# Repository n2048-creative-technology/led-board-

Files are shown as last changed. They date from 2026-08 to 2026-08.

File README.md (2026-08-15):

# LED board

A wall of **584 addressable pixels** — eight identical segments of 73 — that
fills with light one pixel at a time, then breathes. A Seeed XIAO ESP32C3 on a
custom 24 V driver board runs all eight segments from a single hardware timer,
and raises its own Wi-Fi access point so colour, timing and power budget can be
changed from a phone with no app and no internet.

<p align="center">
  System overview: phone over Wi-Fi to a XIAO ESP32C3, one RMT signal fanned out through two SN74AHCT125N buffers to eight LED connectors, with a 24 V supply and an on-board buck converter
</p>

| | |
|---|---|
| Controller | Seeed Studio XIAO ESP32C3 on the `otherworlds-v2` driver board |
| Output | 8 segments × 73 px = **584** WS281x, colour order GBR, 800 kHz, 24 V |
| Frame rate | **63 fps** with the access point running |
| Control | Wi-Fi AP `LED-Board` / `ledboard` → <http://4.3.2.1/> |
| Persistence | All settings in NVS, survive a power cycle |

---

## Contents

- [How it behaves](#how-it-behaves)
- [Web UI](#web-ui)
- [HTTP API](#http-api)
- [Driving 8 outputs from a 2-channel chip](#driving-8-outputs-from-a-2-channel-chip)
- [The driver board](#the-driver-board)
- [Firmware hardware map](#firmware-hardware-map)
- [Power](#power)
- [Build, flash, monitor](#build-flash-monitor)
- [Repository layout](#repository-layout)
- [Status](#status)

---

## How it behaves

Power-up runs a two-stage sequence, identical and in step across all eight
segments:

1. **FILL** — the segment fades up pixel by pixel from the first to the last,
   with a soft leading edge spanning a settable number of pixels.
2. **BREATHE** — once full, brightness cycles between 100% and a settable floor,
   forever.

Turning the lights off runs the fill **backwards**: the pixels withdraw in
exactly the reverse order they arrived, so the last to light is the first to go
dark. Pressing off mid-sweep picks up at the matching front position rather than
snapping, so it stays smooth even if you change your mind halfway.

<p align="center">
  Phase machine FILL to BREATHE to EMPTY to OFF, five snapshots of the fill front travelling along a segment, and the breathing brightness curve
</p>

<p align="center">
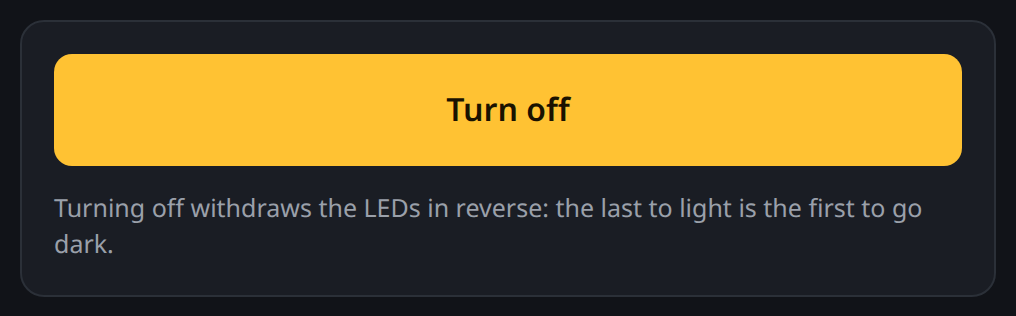
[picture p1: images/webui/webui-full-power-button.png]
Power card showing a bright Turn off button
  
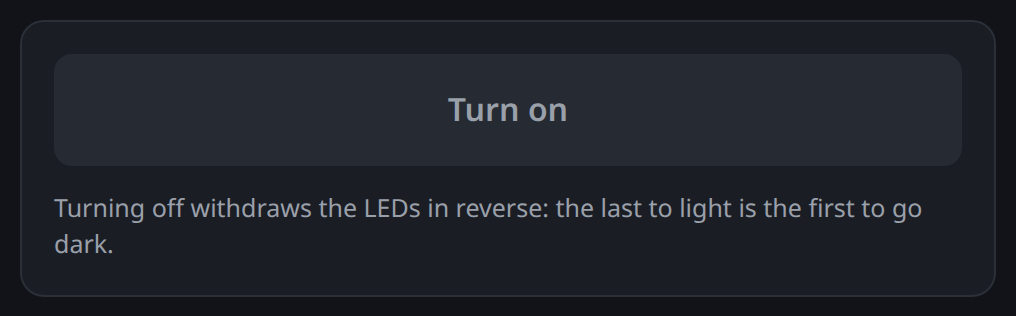
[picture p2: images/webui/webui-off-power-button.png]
The same card with the lights off, showing a dimmed Turn on button
  
</p>

The pixel levels in that diagram are not an illustration — they are computed by
running the firmware's own integer maths (`renderFrontAt()`, `breatheWave()` and
NeoPixel's gamma-2.6 table) outside the chip. The fade is gamma-corrected so it
ramps evenly to the eye instead of spending most of its apparent brightness in
the first few percent.

## Web UI

The board raises its own access point with a captive portal. Join the network
and the "sign in to network" sheet should open the UI by itself; if not, browse
to the address.

| | |
|---|---|
| SSID | `LED-Board` |
| Password | `ledboard` |
| Address | <http://4.3.2.1/> |

Everything on the page is inline — no CDN is reachable on an access point — so
the colour wheel is drawn on a `<canvas>` rather than pulled from a library.

<p align="center">
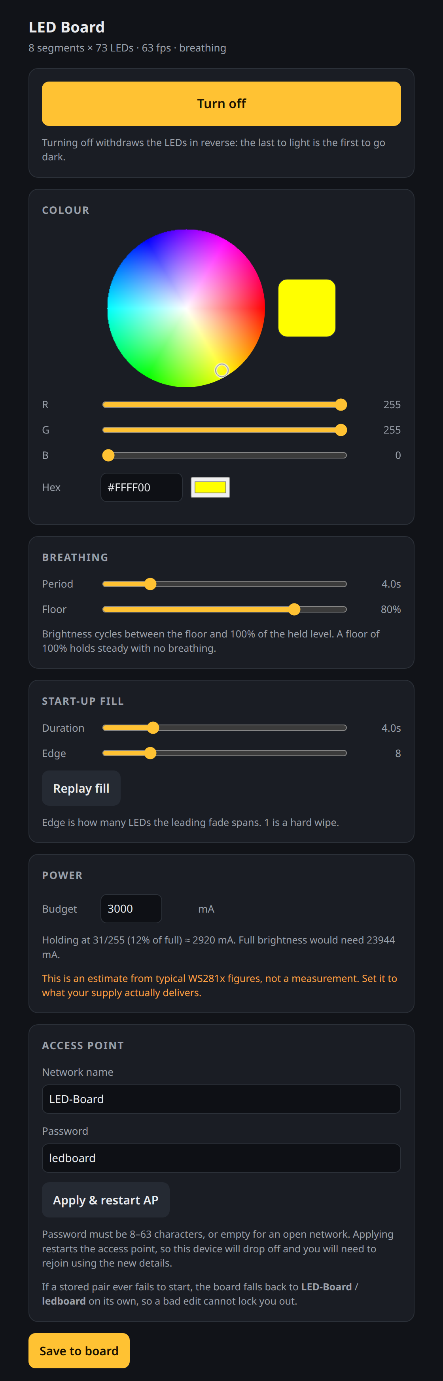
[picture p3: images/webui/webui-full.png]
The full control page: power button, colour wheel with RGB sliders and hex field, breathing controls, start-up fill controls, power budget, and access point settings
  
  &nbsp;&nbsp;
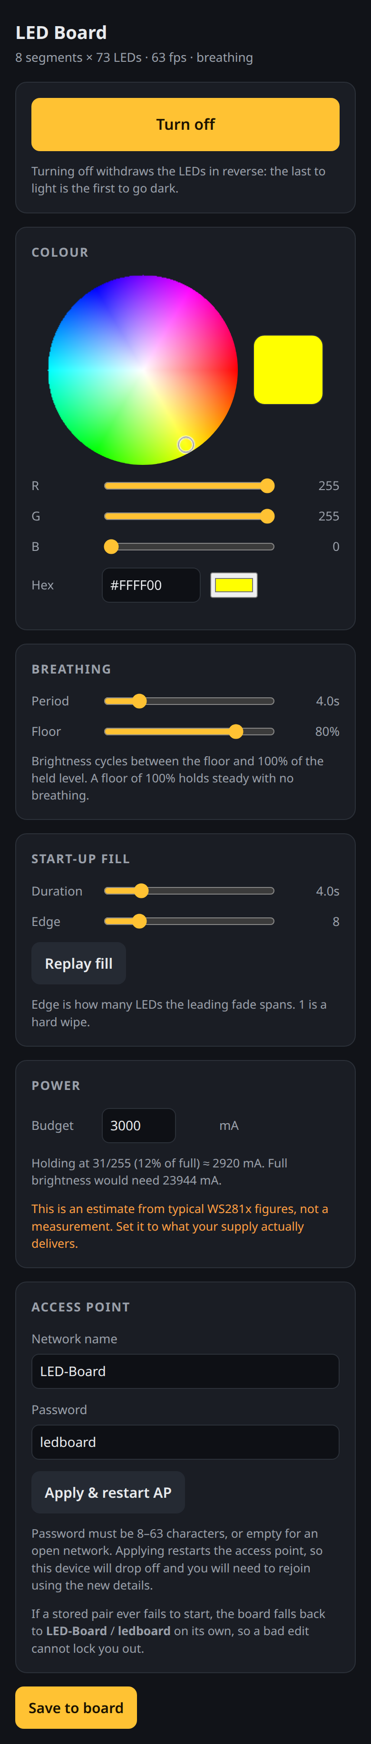
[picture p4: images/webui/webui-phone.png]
The same page at phone width, laying out in a single column
  
</p>

<sub>Left: the page as served, at its 520 px maximum width. Right: the same page
at 390 px — it is a single responsive column, which is how it will actually be
used.</sub>

### Colour

An HSV wheel (drag to pick), R/G/B sliders, a hex field, and the OS-native
colour picker. All four stay in sync, and changes are pushed to the strip live,
debounced at ~60 ms.

<p align="center">
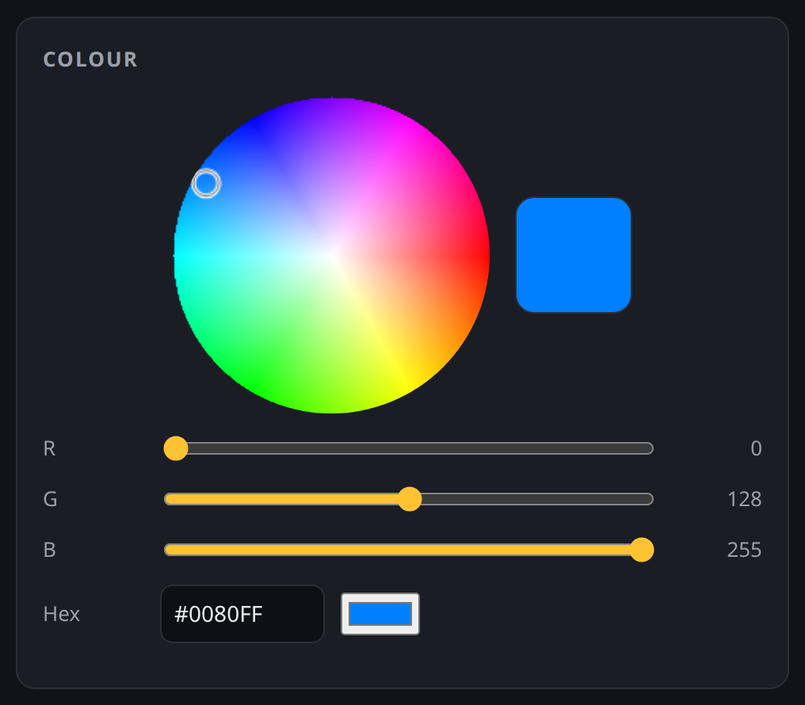
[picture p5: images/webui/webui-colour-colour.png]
Colour card with the wheel, a swatch, R/G/B sliders reading 0/128/255, and the hex field reading #0080FF
  
</p>

### Breathing and start-up fill

<p align="center">
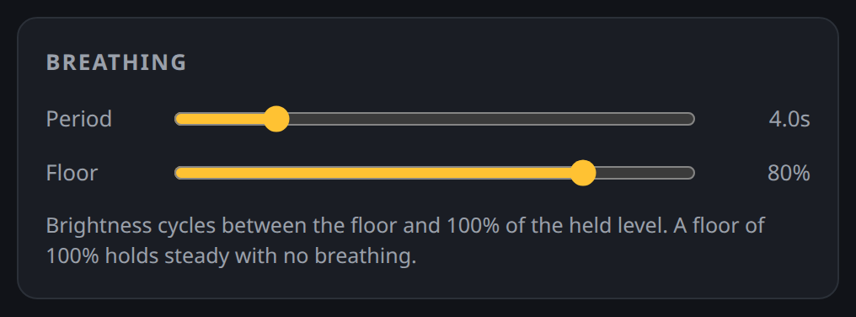
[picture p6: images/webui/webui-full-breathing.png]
Breathing card: period slider at 4.0 s and floor slider at 80 percent
  
</p>

<p align="center">
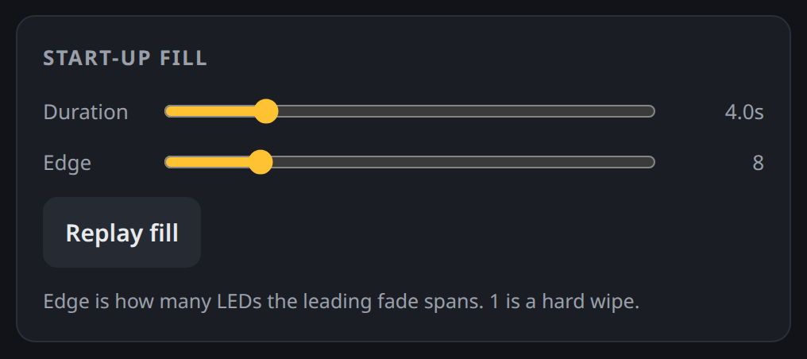
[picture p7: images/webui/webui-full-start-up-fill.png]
Start-up fill card: duration slider at 4.0 s, edge slider at 8 pixels, and a Replay fill button
  
</p>

Period runs 0.5–20 s; a floor of 100% holds steady with no breathing. *Replay
fill* restarts the fill animation so it can be watched again without a reboot.
Edge is how many pixels the leading fade spans — 1 is a hard wipe.

### Power

The budget, with live feedback on the resulting hold level and estimated draw.
The limiter accounts for the *current colour*: red lights one channel, yellow
two, white three, so the achievable brightness changes as you pick. Read
[Power](#power) before trusting the milliamp figure on this 24 V board.

<p align="center">
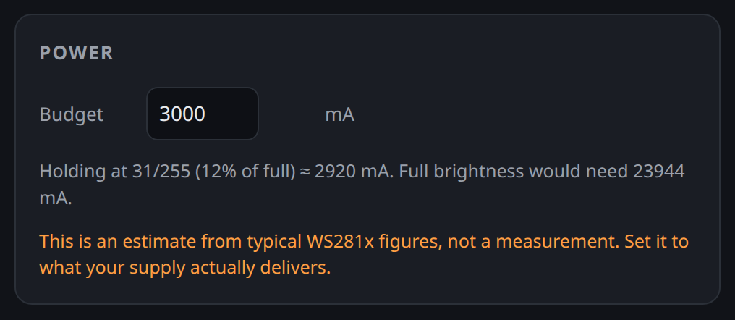
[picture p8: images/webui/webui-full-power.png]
Power card at a 3000 mA budget, reporting a hold of 31 of 255 and about 2920 mA
  
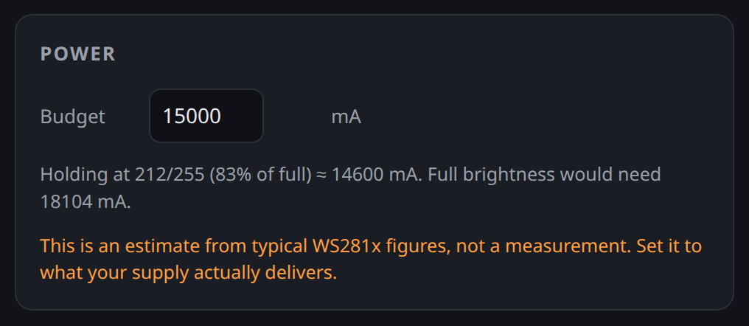
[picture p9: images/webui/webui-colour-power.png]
Power card at a 15000 mA budget, reporting a hold of 212 of 255 and about 14600 mA
  
</p>

<sub>The same card at a 3000 budget (left) and 15000 with a blue-ish colour
selected (right). Both numbers come from the firmware's own estimator.</sub>

### Access point — you cannot lock yourself out

<p align="center">
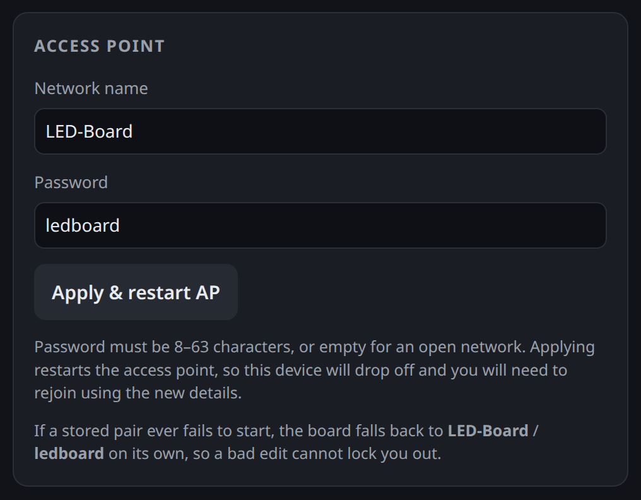
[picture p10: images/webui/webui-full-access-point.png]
Access point card with editable network name and password fields and an Apply and restart AP button
  
</p>

Credentials are validated server-side before being stored: SSID 1–32 characters,
password empty for an open network or 8–63 characters. A 1–7 character password
is rejected, since no access point will start with one. On top of that, if a
stored pair ever fails to bring the AP up, the board falls back to `LED-Board` /
`ledboard` by itself. **Recovering never requires reflashing over USB.**

Applying restarts the radio, so the phone will drop off and must rejoin with the
new details. The HTTP reply is sent ~400 ms before the restart, so the browser
always sees the response.

### Saving

Changes apply live. **Save to board** writes them to NVS so they survive a power
cycle; without saving, the board reverts to its defaults on reboot — including
the on/off state, so a board saved "off" comes back off.

## HTTP API

Handy for scripting or an external controller. All values are clamped
server-side, so out-of-range input is safe.

| Endpoint | Purpose |
|---|---|
| `GET /api/state` | Current settings, hold level, estimated mA, fps, phase |
| `GET /api/set?r=&g=&b=&bp=&bm=&fd=&fe=&pb=` | Set any subset; returns the new state |
| `GET /api/power?on=0\|1` | Turn off (reverse withdraw) or on (fill) |
| `GET /api/ap?ssid=&pass=` | Change AP credentials; `400` if invalid |
| `GET /api/fill` | Restart the fill animation |
| `GET /api/save` | Persist current settings to NVS |

Parameters: `r` `g` `b` 0–255 · `bp` breathe period ms 200–120000 · `bm` breathe
floor % 0–100 · `fd` fill duration ms 100–120000 · `fe` fill edge px 1–73 ·
`pb` power budget 100–40000.

`phase` reports `filling`, `breathing`, `emptying` or `off`.

```console
$ curl "http://4.3.2.1/api/state"
{"on":true,"ssid":"LED-Board","pass":"ledboard","r":255,"g":255,"b":0,
 "bp":4000,"bm":80,"fd":4000,"fe":8,"pb":3000,"hold":31,"ma":2920,
 "maFull":23944,"fps":63,"phase":"breathing"}
```

Wi-Fi does not disturb the LED output — the strips are driven by the RMT
peripheral in hardware, and the frame rate stayed at 62–63 fps with the AP up
and a client connected.

## Driving 8 outputs from a 2-channel chip

The ESP32-C3 has only **2 RMT TX channels**, which rules out both obvious
approaches. The firmware instead transmits **one** segment's worth of data on a
single RMT channel bound to GPIO3, then uses the GPIO matrix
(`esp_rom_gpio_connect_out_signal`) to route that same output signal to the
other seven pins. Every segment gets an identical, hardware-timed waveform, and
a frame costs one transmission (~2.2 ms) instead of eight.

<p align="center">
  Frame buffer to one RMT TX channel to the GPIO matrix, mirrored out to eight GPIOs, with a comparison of three driver approaches
</p>

**The trade-off:** all 8 segments necessarily show the *same* content. That is
exactly what this piece wants. If independent per-segment animation is ever
needed, the options are:

- **2 independent strips** via FastLED (the chip's real RMT limit), or
- **8 independent strips** via a parallel bit-bang driver, computing an 8-bit
  GPIO mask per bit period — all eight pins live in one 32-bit output register,
  so this is feasible but needs cycle-accurate timing work, or
- **a chip with more RMT channels** — ESP32-S3 has 4, the original ESP32 has 8.

## The driver board

KiCad project: [`electronics/otherworlds-v2.kicad_pro`](electronics/otherworlds-v2.kicad_pro).
Two-layer, **98.7 × 90.9 mm**, 1.6 mm, four M4 mounting holes, through-hole
throughout so it can be built by hand.

<p align="center">
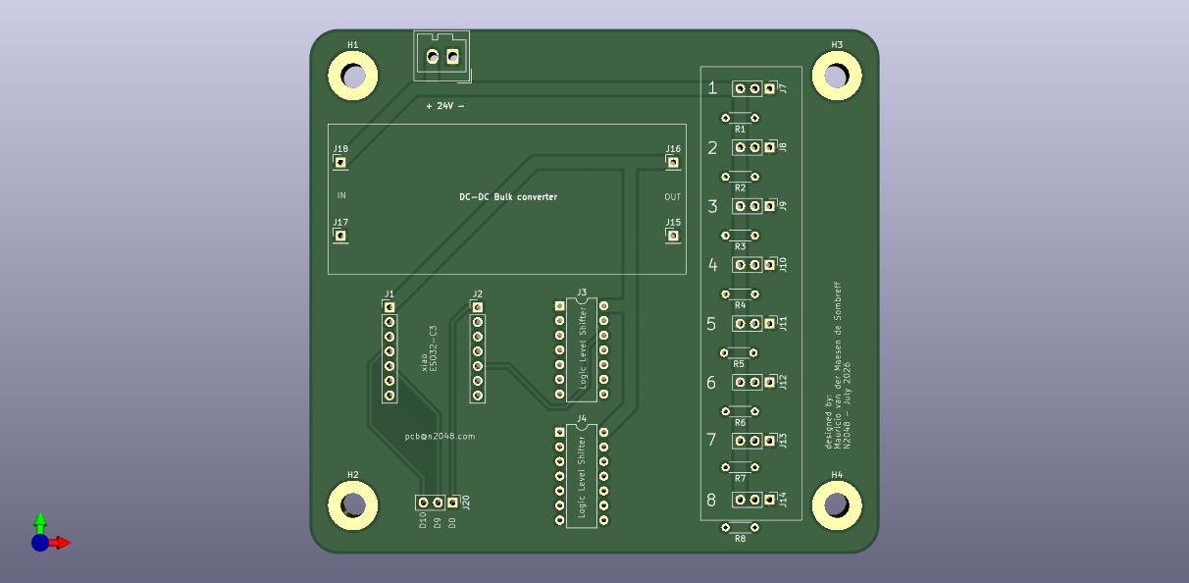
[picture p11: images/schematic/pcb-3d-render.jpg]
3D render of the driver board: 24 V Wago input top left, DC-DC buck converter area, XIAO on two 7-pin headers, two level shifter DIPs, and eight numbered 3-pin LED connectors with series resistors down the right edge
  
</p>

<p align="center">
  KiCad schematic: XIAO headers, two SN74AHCT125N level shifters with eight 220 ohm series resistors, eight 3-pin LED connectors, DC-DC buck converter headers, and a 24 V input
</p>

<sub>Exported from
<a href="electronics/otherworlds-v2.kicad_sch">otherworlds-v2.kicad_sch</a> with
<code>kicad-cli</code>. Also available as
<a href="images/schematic/otherworlds-v2.pdf">PDF</a>, and the layers as
<a href="images/schematic/pcb-front.svg">front</a> /
<a href="images/schematic/pcb-back.svg">back</a> SVG.</sub>

### Signal path

<p align="center">
  One channel: XIAO D1 into an SN74AHCT125N buffer, out through a 220 ohm resistor to connector J7 pin 2, with 24 V on pin 3 and a shared ground
</p>

Each of the eight channels is the same four parts:

**XIAO Dn → SN74AHCT125N buffer → 220 Ω → LED connector pin 2.**

The buffers run from the on-board 5 V rail. AHCT-family logic takes a 3.3 V
input as a valid high and drives a full 5 V output, which is what gets the data
line clear of a WS281x input threshold — the XIAO's own 3.3 V swing is marginal
and fails intermittently on a long lead.

Only the data line passes through the board's logic side; **+24 V goes straight
from the Wago input to pin 3 of every LED connector** and never touches it.

### Bill of materials

From [`electronics/production/bom.csv`](electronics/production/bom.csv):

| Ref | Part | Qty | Footprint |
|---|---|---|---|
| J3, J4 | SN74AHCT125N quad buffer | 2 | DIP-14, 7.62 mm |
| R1–R8 | 220 Ω | 8 | Axial DIN0204, 5.08 mm |
| J1, J2 | 1×7 pin header — the XIAO | 2 | 2.54 mm vertical |
| J7–J14 | 1×3 pin header — LED segments 1–8 | 8 | 2.54 mm vertical |
| J15–J18 | 1×1 pin header — buck converter module | 4 | 2.54 mm vertical |
| J19 | Wago 734-132 — 24 V input | 1 | 3.50 mm vertical |
| J20 | 1×3 pin header — D0/D9/D10 breakout | 1 | 2.54 mm vertical |
| H1–H4 | M4 mounting hole, plated | 4 | 4.3 mm |

The DC-DC buck converter is a **module**, not a fitted part: it sits on the four
single-pin headers (`J18`/`J17` in, `J16`/`J15` out), so it can be sized to the
5 V load and swapped without touching the board.

`J20` breaks out D0, D9 and D10 — the three pins the LED channels do not use.
D0/GPIO2 and D9/GPIO9 are strapping pins; read
[the pinout notes](firmware/docs/xiao-esp32c3-pinout.md) before hanging anything
off them.

### Connector map

Traced through the netlist exported from the committed schematic — not read off
the drawing:

| Connector (silkscreen) | J7 (1) | J8 (2) | J9 (3) | J10 (4) | J11 (5) | J12 (6) | J13 (7) | J14 (8) |
|---|---|---|---|---|---|---|---|---|
| Net | L1 | L2 | L3 | L4 | L5 | L6 | L7 | L8 |
| Resistor | R1 | R2 | R3 | R4 | R5 | R6 | R7 | R8 |
| Buffer | J3 | J3 | J3 | J3 | J4 | J4 | J4 | J4 |
| XIAO pin | D1 | D2 | **D4** | **D3** | D5 | D6 | **D8** | **D7** |
| GPIO | 3 | 4 | 6 | 5 | 7 | 21 | 8 | 20 |

Note the two crossed pairs: J9/J10 are fed by D4/D3, and J13/J14 by D8/D7. That
is harmless here — every output carries the identical waveform, so which pin
lands on which connector cannot change what the wall does — but it is worth
knowing before probing a channel with a scope.

Every LED connector is wired the same way: **pin 1 = GND, pin 2 = data,
pin 3 = +24 V**.

> ⚠️ **The working copy of the schematic is mid-edit and currently inconsistent.**
> In `HEAD` every data label appears exactly twice (once at the XIAO header,
> once at a buffer input). In the uncommitted file, `D1` and `D2` appear only
> once each while `D7` and `D8` appear three times — the two labels at J3's
> first inputs now read D7/D8, so those buffers would be driven in parallel with
> J4's and D1/D2 would drive nothing. Because all eight channels carry the same
> waveform, the piece would still *look* correct, which is what makes it worth
> catching. The table above comes from `HEAD`; re-run
> `bash scripts-tools/export-kicad.sh` and re-check it once the edits land.

## Firmware hardware map

| | |
|---|---|
| Board | Seeed Studio XIAO ESP32C3 (`seeed_xiao_esp32c3`) |
| MCU | ESP32-C3, single-core RISC-V @ 160 MHz, 4 MB flash |
| Platform | pioarduino `espressif32` 54.3.20 — Arduino core 3.2.0, ESP-IDF 5.4 |
| LED library | Adafruit NeoPixel 1.15.5 (FastLED 3.10.3 kept for colour helpers) |
| Strip | WS281x, 800 kHz, colour order **GBR**, 24 V |
| Segments | 8 × 73 px = 584 total |
| Data pins | D1–D8 = GPIO 3, 4, 5, 6, 7, 21, 20, 8 |
| Serial | Native USB Serial/JTAG, 115200 baud |

Strip parameters (WS281x / GBR / 73) were taken from a WLED configuration
confirmed working on this exact hardware — worth keeping as the reference if
anything ever regresses. `73` counts **control ICs**, not LED packages: a 24 V
strip usually groups several physical LEDs behind each addressable pixel.

D1/GPIO3 carries the master signal because it is **not** a strapping pin, so an
attached strip cannot interfere with boot the way D0/D8/D9 could.

> **There is no GPIO22 on the ESP32-C3** — its GPIO range is 0–21. D7 is
> **GPIO20** (UART0 RX), which is what the seventh segment uses.

Full pin map, strapping-pin traps and the BOOT-button recovery procedure:
[firmware/docs/xiao-esp32c3-pinout.md](firmware/docs/xiao-esp32c3-pinout.md).

## Power

Adafruit NeoPixel has no power management of its own, so the firmware includes a
limiter: it finds the brightest scaling of the chosen colour that fits
`powerBudgetMa` and holds there, which is why the UI reports a *hold level*
rather than simply obeying the brightness you asked for.

### The estimator models a 5 V strip

> ⚠️ **The milliamp figures the firmware reports are a 5 V-strip model** —
> 20 mA per channel per pixel at full, plus 1 mA idle per controller IC. **This
> board runs the strips at 24 V**, where the current drawn from the supply is a
> different number entirely (roughly the strip's rated W/m × length ÷ 24 V).
>
> So on this hardware, treat the budget as **a brightness cap in the firmware's
> own units**, not as amps at the PSU. Size the actual supply from the strip's
> rating, measure the real draw, and then pick the budget that lands on a
> brightness you can afford.

What the limiter does with a given budget, for yellow (255, 255, 0) across all
584 pixels — these are the numbers the UI will show:

| Budget | Hold level | Fraction of full | Reported draw |
|---|---|---|---|
| 3000 (default) | 31/255 | 12% | 2920 |
| 5000 | 50/255 | 20% | 4672 |
| 10000 | 108/255 | 42% | 9928 |
| 15000 | 159/255 | 62% | 14600 |
| 20000 | 216/255 | 85% | 19856 |
| 24000+ | 255/255 | 100% | 23944 |

Colour changes the arithmetic completely. At full brightness the estimator
reports roughly **12264** for a single-channel colour (red, green, blue),
**23944** for a two-channel one (yellow, cyan, magenta) and **35624** for white
— so the same budget buys a much brighter red than white.

Whatever the voltage, two things still hold: **inject power at both ends of each
segment** (and mid-run on long ones), and expect a visible colour shift toward
red wherever the supply sags.

## Build, flash, monitor

```bash
cd firmware
pio run                    # build
pio run -t upload          # build + flash
pio device monitor         # 115200 baud
```

Last verified build (2026-08-15, `pio run`):

```
RAM:   [=         ]  11.6% (used 37944 bytes from 327680 bytes)
Flash: [========  ]  77.6% (used 1017378 bytes from 1310720 bytes)
========================= [SUCCESS] Took 12.66 seconds =========================
```

### Testing without a strip

The firmware self-reports over serial, so it can be validated with nothing
attached — the RMT peripheral will happily clock data into thin air, and the
per-2-second heartbeat reports phase, level, frame rate, estimated draw and the
number of connected Wi-Fi clients.

```
XIAO ESP32C3 - LED board
8 segments x 73 LEDs = 584 total | WS281x 800 kHz, order GBR
Pins: D1=GPIO3 D2=GPIO4 D3=GPIO5 D4=GPIO6 D5=GPIO7 D6=GPIO21 D7=GPIO20 D8=GPIO8
  RMT signal 87 on GPIO3 -> mirrored to: GPIO4 GPIO5 GPIO6 GPIO7 GPIO21 GPIO20 GPIO8
Colour 255,255,0 | budget 3000 mA -> hold 31/255 (est. 2920 mA, full 23944 mA)
AP "LED-Board" up -> http://4.3.2.1/  (password: ledboard)
PHASE: FILL
[    2000 ms] FILL    | level  31/255 | 62 fps | est. 2920 mA | clients 0
PHASE: BREATHE
[    4000 ms] BREATHE | level  27/255 | 63 fps | est. 2607 mA | clients 1
```

<sub>Format derived from the <code>Serial.printf</code> calls in
<code>main.cpp</code>; the RMT signal number is whatever the driver was
assigned. Not yet captured from hardware — see <a href="#status">Status</a>.</sub>

Three things to check first if something looks wrong:

- **Garbled colours or flicker** → wrong chipset timing. `PIXEL_TYPE` is
  `NEO_GBR + NEO_KHZ800`.
- **Colours swapped** (yellow shows as something else) → wrong byte order. Swap
  the letters in the `NEO_GBR` half of `PIXEL_TYPE`; common variants are `GRB`,
  `RGB` and `BRG`.
- **`FAN-OUT FAILED: GPIO3 has no peripheral signal`** → the RMT channel never
  bound to the master pin, so only segment 1 would light. Everything downstream
  depends on that line succeeding.

## Repository layout

```
electronics/          KiCad project "otherworlds-v2" — schematic, PCB, production files
  production/         Gerbers, BOM, positions (JLCPCB fabrication toolkit output)
firmware/             PlatformIO project
  src/main.cpp        the whole firmware: animation, power limiter, AP, web UI
  docs/               pinout and GPIO caveats
images/
  diagrams/           SVG diagrams (generated)
  schematic/          KiCad exports + the 3D render
  webui/              web UI screenshots (generated)
scripts-tools/        the generators for everything in images/
```

### Regenerating the documentation assets

All three generators are deterministic; only the KiCad exports need KiCad
installed, and none of them need hardware:

```bash
python3 scripts-tools/mkshots.py      # -> images/webui/*.png
python3 scripts-tools/mkdiagrams.py   # -> images/diagrams/*.svg
bash    scripts-tools/export-kicad.sh # -> images/schematic/*
```

`mkshots.py` lifts the page straight out of the `R"HTML(...)HTML"` literal in
`firmware/src/main.cpp`, replaces `window.fetch` with a shim that reimplements
the `/api/*` handlers — including the integer power maths — and screenshots the
result in headless Chrome. So the screenshots track the firmware: change the UI,
re-run, and the README is current. `mkdiagrams.py` likewise computes the
animation diagram from the firmware's own rendering maths. Details in
[scripts-tools/README.md](scripts-tools/README.md).

## Status

| Step | Status |
|---|---|
| PCB designed, fabrication files exported | ✅ `otherworlds-v2`, July 2026 |
| Builds for `seeed_xiao_esp32c3` | ✅ 2026-08-15 — RAM 11.6%, flash 77.6% |
| Web UI rendered and exercised | ✅ against a faithful mock of the device API |
| Flashed and run on hardware | ⏳ pending — no board on USB at time of writing |
| Board brought up with strips attached | ⏳ pending |
| Measured current draw | ⏳ pending — all power figures are estimates, and the estimator assumes 5 V |

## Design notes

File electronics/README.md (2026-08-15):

# Electronics — `otherworlds-v2`

KiCad 9 project for the LED driver board: a XIAO ESP32C3 carrier that buffers
its eight data outputs to 5 V and hands them to eight 24 V LED segments.

Open [`otherworlds-v2.kicad_pro`](otherworlds-v2.kicad_pro). Rendered exports of
the schematic and layers live in [`../images/schematic/`](../images/schematic)
and are regenerated with `bash ../scripts-tools/export-kicad.sh`.

| | |
|---|---|
| Size | 98.7 × 90.9 mm, 1.6 mm, 2 layer |
| Mounting | 4 × M4 plated holes (H1–H4) |
| Assembly | Through-hole throughout — hand-solderable |
| Input | 24 V via Wago 734-132 (J19) |
| Logic supply | DC-DC buck module on J15–J18, 24 V → 5 V |

## Signal path

Eight identical channels:

```
XIAO Dn ─► SN74AHCT125N (J3 for D1-D4, J4 for D5-D8) ─► 220 Ω (Rn) ─► LED connector pin 2
```

AHCT logic runs from 5 V and accepts 3.3 V as a valid high, so it both level
shifts and buffers: the strip sees a full 5 V edge instead of the XIAO's
marginal 3.3 V. The series resistor damps reflections and sits at the driver
end of the line.

+24 V runs from J19 straight to pin 3 of every LED connector. It never enters
the logic side of the board.

## Connector map

Traced through the netlist of the committed schematic:

| Connector | J7 (1) | J8 (2) | J9 (3) | J10 (4) | J11 (5) | J12 (6) | J13 (7) | J14 (8) |
|---|---|---|---|---|---|---|---|---|
| Net | L1 | L2 | L3 | L4 | L5 | L6 | L7 | L8 |
| Resistor | R1 | R2 | R3 | R4 | R5 | R6 | R7 | R8 |
| Buffer | J3 | J3 | J3 | J3 | J4 | J4 | J4 | J4 |
| XIAO pin | D1 | D2 | **D4** | **D3** | D5 | D6 | **D8** | **D7** |
| GPIO | 3 | 4 | 6 | 5 | 7 | 21 | 8 | 20 |

J9/J10 and J13/J14 are fed by crossed pairs. Harmless — the firmware drives all
eight outputs with one identical waveform — but worth knowing at the bench.

LED connectors are all **pin 1 = GND, pin 2 = data, pin 3 = +24 V**.

> ⚠️ The working copy is currently mid-edit: `D1`/`D2` appear once each and
> `D7`/`D8` three times, i.e. J3's first two inputs are labelled D7/D8 rather
> than D1/D2. In `HEAD` every label appears exactly twice. See the root
> [README](../README.md#connector-map).

Other headers:

| Ref | Purpose |
|---|---|
| J1 / J2 | XIAO ESP32C3, 1×7 each |
| J15–J18 | Buck module: J18/J17 = 24 V in, J16/J15 = 5 V out |
| J19 | 24 V input, Wago cage clamp |
| J20 | Breakout of the three unused pins: D0, D9, D10 |

⚠️ D0/GPIO2 and D9/GPIO9 on J20 are **strapping pins**. Anything wired there can
stop the board booting — read
[../firmware/docs/xiao-esp32c3-pinout.md](../firmware/docs/xiao-esp32c3-pinout.md)
first.

## Fabrication

[`production/`](production) holds the JLCPCB fabrication-toolkit output:
[`otherworlds-v2.zip`](production/otherworlds-v2.zip) (gerbers),
[`bom.csv`](production/bom.csv), [`positions.csv`](production/positions.csv),
[`designators.csv`](production/designators.csv) and an IPC netlist. Settings are
in [`fabrication-toolkit-options.json`](fabrication-toolkit-options.json).

Everything is through-hole, so the BOM carries no LCSC part numbers — it is a
hand-assembly list, not an assembly-service one.

## Sizing the supply

Work from the strip's rating, not from the firmware's estimate: the firmware's
milliamp figures model a 5 V strip, while these segments run at 24 V. Take the
strip's W/m × total length ÷ 24 V, add margin, and fuse the input. Inject at
both ends of each segment.

Details, and what the firmware's budget number actually controls, in the root
[README](../README.md#power).

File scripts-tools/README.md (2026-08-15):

# Documentation generators

Everything in [`images/`](../images) is generated by these scripts. Nothing here
needs hardware attached.

| Script | Output | What it does |
|---|---|---|
| `mkshots.py` | `images/webui/*.png` | Screenshots of the ESP32-served web UI |
| `mkdiagrams.py` | `images/diagrams/*.svg` | The four README diagrams |
| `export-kicad.sh` | `images/schematic/*` | Schematic SVG + PDF, PCB layer SVGs, 3D render |
| `rasterize.sh` | `*.png` beside each SVG | Preview render of an SVG, via Chrome |

```bash
python3 scripts-tools/mkshots.py
python3 scripts-tools/mkdiagrams.py
bash    scripts-tools/export-kicad.sh
```

Requires `google-chrome` on `PATH`, Pillow for `mkshots.py`, and KiCad for
`export-kicad.sh` — it finds either `kicad-cli` or the snap's
`kicad.kicad-cli`. The snap is confined to `$HOME`, which is why the export
script always writes inside the repo.

## How the screenshots stay honest

`mkshots.py` does not keep a copy of the page. It extracts the
`R"HTML(...)HTML"` literal out of `firmware/src/main.cpp` at run time, then
injects a shim that replaces `window.fetch` with a reimplementation of the
firmware's `/api/*` handlers — including the integer power maths
(`estimateMilliamps` / `computeHoldLevel`), so the hold level and mA readouts on
screen are the numbers the board would actually report. Change the UI in the
firmware, re-run, and the README is current.

The variants captured (default yellow, lights off, another colour at a 15 A
budget, phone width) are the `shoot(...)` calls at the bottom of the file. Card
crops come from bounding boxes measured in the live page, not fixed pixel
offsets, so they survive layout changes.

## How the diagrams stay honest

`mkdiagrams.py` writes SVG directly. The animation diagram is not drawn by hand:
`strip_levels()` and `breathe_wave()` are line-by-line ports of `renderFrontAt()`
and `breatheWave()` from `main.cpp`, gamma table included, so the LED gradients
and the breathing curve are the firmware's real output.

## Do not use ImageMagick on these SVGs

`convert` falls back to ImageMagick's internal SVG renderer here, which silently
drops `fill-opacity` (every LED renders fully lit) and mis-measures text.
`rasterize.sh` goes through Chrome instead:

```bash
scripts-tools/rasterize.sh images/diagrams/animation.svg
```

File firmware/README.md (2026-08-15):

# LED board

Firmware for a Seeed **XIAO ESP32C3** driving addressable RGB LED strips.

Current behaviour, across **8 identical strip segments** (73 LEDs each, 584
total) on D1–D8:

1. **FILL** — every segment fades up to bright yellow, LED by LED from the
   first to the last, with a soft leading edge. All 8 segments run this in
   parallel and in step.
2. **BREATHE** — once full, brightness breathes between 100% and 80% of the
   held level, forever.

## Wi-Fi control

The board raises its own access point with a captive portal, so it can be
controlled from a phone with no app and no internet.

| | |
|---|---|
| SSID | `LED-Board` |
| Password | `ledboard` |
| Address | http://4.3.2.1/ |

Join the network and the "sign in" sheet should open the UI automatically; if
not, browse to the address. Everything on the page is inline — no CDN is
reachable on an AP, so the colour wheel is drawn on a `<canvas>` rather than
pulled from a library.

The UI offers:

- **On / off** — turning off runs the fill animation **backwards**, so the
  LEDs withdraw in exactly the reverse order they arrived: the last LED to
  light is the first to go dark. Pressing the button mid-sweep picks up at the
  matching front position rather than snapping, so it stays smooth even if you
  change your mind halfway.
- **Colour** — an HSV wheel (drag to pick), R/G/B sliders, a hex field, and
  the OS-native colour picker. All four stay in sync.
- **Breathing** — cycle period (0.5–20 s) and floor (0–100%). A floor of 100%
  holds steady with no breathing.
- **Start-up fill** — duration, leading-edge softness in LEDs, and a *Replay
  fill* button to watch it again without a reboot.
- **Power** — the budget in mA, with live feedback on the resulting hold level
  and estimated draw. The limiter accounts for the *current colour*: red uses
  one channel, yellow two, white three, so the achievable brightness changes
  as you pick.
- **Access point** — editable network name and password. Applying restarts the
  radio, so you will be disconnected and must rejoin with the new details.

### You cannot lock yourself out of the AP

Credentials are validated server-side before being stored (SSID 1–32 chars,
password empty for an open network or 8–63 chars — a 1–7 char password is
rejected, since no AP will start with one). On top of that, if a stored pair
ever fails to bring the AP up, the board falls back to `LED-Board` /
`ledboard` by itself. Recovering never requires reflashing over USB.

Changes apply live (debounced ~60 ms). **Save to board** writes them to NVS so
they survive a power cycle; without saving, the board reverts to defaults on
reboot.

### HTTP API

Handy for scripting or an external controller:

| Endpoint | Purpose |
|---|---|
| `GET /api/state` | Current settings, hold level, estimated mA, fps, phase |
| `GET /api/set?r=&g=&b=&bp=&bm=&fd=&fe=&pb=` | Set any subset; returns new state |
| `GET /api/power?on=0\|1` | Turn off (reverse withdraw) or on (fill) |
| `GET /api/ap?ssid=&pass=` | Change AP credentials; 400 if invalid |
| `GET /api/fill` | Restart the fill animation |
| `GET /api/save` | Persist current settings to NVS |

`phase` reports `filling`, `breathing`, `emptying` or `off`.

All values are clamped server-side, so out-of-range input is safe.

Wi-Fi does not disturb the LED output — the strips are driven by the RMT
peripheral in hardware, and the frame rate stayed at 62 fps with the AP
running.

## ⚠️ Power: yellow at this scale is expensive

584 LEDs, and **yellow lights two channels per LED**. Full-brightness yellow
across all segments is an estimated **~24 A at 5 V (~120 W)**.

The firmware includes a limiter (Adafruit NeoPixel has no power management of
its own) that computes the brightest yellow fitting `POWER_BUDGET_MA` and
holds there. At the placeholder **3000 mA** it settles on level **31/255 —
about 12% of full**, which is not "bright" by any reasonable reading.

**Set `POWER_BUDGET_MA` in [src/main.cpp](src/main.cpp) to what your supply
actually delivers.** Roughly what each budget buys:

| PSU budget | Hold level | Fraction of full |
|---|---|---|
| 3 A (placeholder) | 31/255 | ~12% |
| 10 A | ~106/255 | ~42% |
| 15 A | ~160/255 | ~63% |
| 20 A | ~213/255 | ~84% |
| 24 A+ | 255/255 | 100% |

Injecting power at both ends of each segment (and mid-run for long ones) is
also worth planning — 24 A does not travel far down a strip's copper without
a visible voltage drop and a colour shift toward red.

## Driving 8 outputs from a 2-channel chip

The ESP32-C3 has only **2 RMT TX channels**, which rules out both obvious
approaches:

| Approach | Result |
|---|---|
| FastLED 3.10.3, 8 controllers | ❌ `no free tx channels`, then a Guru Meditation panic. FastLED pins one RMT channel per controller for its lifetime — hard limit of 2 strips. Its `README_WORKER_POOL.md` describes transparent N>K sharing, but **that implementation is not in the source**. |
| Adafruit NeoPixel, 8 instances | ⚠️ Works — it re-binds a single channel per pin on each show — but the teardown/setup cost measured **3 fps** at 8×73 LEDs. |
| **1 RMT channel + GPIO matrix fan-out** | ✅ **63 fps.** What this firmware does. |

The working approach transmits **one** strip's worth of data on one RMT
channel bound to GPIO3, then uses the GPIO matrix
(`esp_rom_gpio_connect_out_signal`) to route that same output signal to the
other seven pins. Every segment gets an identical, hardware-timed waveform,
and a frame costs one transmission (~2.2 ms) rather than eight.

**The trade-off:** all 8 segments necessarily show the *same* content. That is
exactly what this blue pulse wants. If independent per-segment animation is
ever needed, the options are:

- **2 independent strips** via FastLED (the chip's real RMT limit), or
- **8 independent strips** via a parallel bit-bang driver, computing an 8-bit
  GPIO mask per bit period — all eight pins live in one 32-bit output
  register, so this is feasible but needs cycle-accurate timing work, or
- **a chip with more RMT channels** — ESP32-S3 has 4, original ESP32 has 8.

## Hardware

| | |
|---|---|
| Board | Seeed Studio XIAO ESP32C3 (`seeed_xiao_esp32c3`) |
| MCU | ESP32-C3, single-core RISC-V @ 160 MHz, 4 MB flash |
| Platform | pioarduino `espressif32` 54.03.20 — Arduino core 3.2.0, ESP-IDF 5.4 |
| LED library | Adafruit NeoPixel 1.15.5 |
| Strip | WS281x RGB, 800 kHz, colour order **GBR** |
| Segments | 8 × 73 LEDs = 584 total |
| Data pins | D1–D8 = GPIO 3, 4, 5, 6, 7, 21, 20, 8 |
| Serial | Native USB Serial/JTAG, 115200 baud |

Strip parameters (WS281x / GBR / 73) were taken from a WLED configuration
confirmed working on this exact hardware — worth keeping as the reference if
anything regresses.

> **There is no GPIO22 on the ESP32-C3** — its GPIO range is 0–21. D7 is
> **GPIO20** (UART0 RX), which is what the seventh segment uses.

Full pin map and GPIO caveats: [docs/xiao-esp32c3-pinout.md](docs/xiao-esp32c3-pinout.md).

D1/GPIO3 is deliberately chosen: it is **not** a strapping pin, so an attached
strip cannot interfere with boot the way D0/D8/D9 could.

## Wiring

```
XIAO D1 (GPIO3) ──[ 330Ω ]──► DIN   (strip data input — follow the arrows)
XIAO GND ───────────────────── GND  (must be common with the strip PSU)
Strip +V ◄───────────────────  strip power supply (5 V or 12 V — see below)
                               1000 µF across +V/GND at the injection point
```

Five things that actually matter:

1. **Logic level.** WS2812-family chips want `VIH ≈ 0.7 × VDD`, i.e. ~3.5 V on
   a 5 V strip. The XIAO outputs 3.3 V, which is *marginal*. It often works on
   a short lead and fails intermittently on a long one. Robust fixes: a
   74AHCT125/74HCT245 level shifter, or drop the strip supply to ~4.3–4.5 V
   with a series diode so 3.3 V clears the threshold.
2. **Series resistor.** 220–470 Ω on the data line, placed close to the XIAO
   pin, damps reflections.
3. **Bulk capacitor.** 1000 µF electrolytic across the strip's +V/GND at the
   power injection point absorbs switch-on inrush.
4. **Common ground.** The XIAO ground and the strip PSU ground must be tied
   together, or the data signal has no reference.
5. **Power budget.** The XIAO's `5V` pin is just USB VBUS passthrough — the
   whole USB port budget is 500 mA and the board itself eats into that. That
   is roughly 8 LEDs at full white. Anything longer needs its own supply.
   **If the strip is 12 V, it must have its own PSU — never feed 12 V into the
   XIAO.**

The firmware also enforces a software ceiling via
`FastLED.setMaxPowerInVoltsAndMilliamps(5, 500)`, which scales brightness down
automatically rather than browning out. Raise `POWER_MILLIAMPS` in
[src/main.cpp](src/main.cpp) once the strip runs off a dedicated supply.

## Configuration

All in the header block of [src/main.cpp](src/main.cpp):

| Constant | Default | Meaning |
|---|---|---|
| `LED_DATA_PIN` | `D1` | Strip data pin (GPIO3) |
| `LED_CHIPSET` | `SM16703` | FastLED driver — 300/600/300 ns, ~833 kHz |
| `COLOR_ORDER` | `GRB` | Byte order the strip expects |
| `NUM_LEDS` | `30` | Number of control ICs, **not** LED packages |
| `PULSE_PERIOD_MS` | `3000` | One full fade-up + fade-down cycle |
| `PULSE_MAX_BRIGHTNESS` | `200` | Peak of the pulse, 0–255 |

### If the strip is not an SM16703

`LED_CHIPSET` is a single token — swap it for `WS2812B` (250/625/375 ns, the
usual 5 V 5050 strip), `UCS1903` (500/1500/500 ns, 400 kHz), or `SK6812`.
Symptom of a wrong chipset is flicker or garbled colours down the strip.

### If the colours are wrong

`COLOR_ORDER` is the culprit. The boot self-test makes this trivial to
diagnose — it lights the strip red, then green, then blue, announcing each on
serial. If "BLUE" shows green, swap the last two letters of `COLOR_ORDER`;
common variants are `GRB`, `RGB`, and `BRG`.

## Build, flash, monitor

```bash
pio run                    # build
pio run -t upload          # build + flash
pio device monitor         # 115200 baud
```

## Testing

The firmware self-reports over serial, so it can be validated with no strip
attached — FastLED will happily clock data into thin air. Expected output:

```
XIAO ESP32C3 - FastLED blue pulse
FastLED 3.10.3 | chipset SM16703 | order GRB
Data pin D1 = GPIO3 | 30 LEDs | pulse period 3000 ms
Power limit 5 V / 500 mA
Colour-order self-test (RED, GREEN, BLUE):
  self-test: strip should be RED
  self-test: strip should be GREEN
  self-test: strip should be BLUE
  if those colours were wrong, change COLOR_ORDER in main.cpp
Pulsing blue.
[    1234 ms] blue level  87/255 | 60 fps | ~102 mA
```

The per-second heartbeat reports the current blue level, the achieved frame
rate, and FastLED's own estimate of unscaled strip current — useful for
sanity-checking the power budget before committing to a strip length.

### Verification status

| Step | Status |
|---|---|
| Builds for `seeed_xiao_esp32c3` | ✅ RAM 4.0%, flash 23.2% |
| Flashed and run on hardware | ⏳ pending — board not on USB at time of writing |

The earlier all-pin blink sketch *was* flashed and verified on this board
(2026-08-15, `/dev/ttyACM0`); the FastLED version has not yet been.

## Notes

- **RMT channels.** The ESP32-C3 has only **2 RMT TX channels**, so FastLED
  can drive at most 2 parallel strips on this chip. One strip is comfortable.
- **RMT4 vs RMT5.** ESP-IDF 5.x selects FastLED's RMT5 backend automatically.
  The two backends cannot coexist in one sketch — IDF panics at boot if both
  try to initialise.
- **No `LED_BUILTIN`.** The XIAO ESP32C3's on-board LEDs are power and
  battery-charge indicators, hardwired.
- **USB CDC.** `Serial` is the native USB Serial/JTAG port, so the serial
  device disappears and re-enumerates on every reset/reflash. That is normal.

## Layout

```
src/     firmware sources
include/ headers
lib/     project-private libraries
test/    unit tests
docs/    datasheets, pinouts, reference notes
```

`kicad/`, `openscad/`, `3d-models/` and `images/` to be added as the board and
enclosure work starts.

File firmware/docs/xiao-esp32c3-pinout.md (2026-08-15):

# Seeed XIAO ESP32C3 — pinout & GPIO notes

Sources: [Seeed XIAO ESP32C3 wiki](https://wiki.seeedstudio.com/XIAO_ESP32C3_Getting_Started/)
and the Arduino core variant header
`~/.platformio/packages/framework-arduinoespressif32/variants/XIAO_ESP32C3/pins_arduino.h`
(both checked 2026-08-15 — they agree).

## Broken-out digital pins

The castellated edge exposes 11 digital pins plus 5V, 3V3 and GND.

| Board pin | GPIO | Alternate functions |
|---|---|---|
| D0 | GPIO2 | A0 / ADC1_CH2 — **strapping pin** |
| D1 | GPIO3 | A1 / ADC1_CH3 |
| D2 | GPIO4 | A2 / ADC1_CH4, FSPIHD, MTMS (JTAG) |
| D3 | GPIO5 | ADC2_CH0, FSPIWP, MTDI (JTAG) |
| D4 | GPIO6 | SDA, FSPICLK, MTCK (JTAG) |
| D5 | GPIO7 | SCL, FSPID, MTDO (JTAG) |
| D6 | GPIO21 | UART0 TX |
| D7 | GPIO20 | UART0 RX |
| D8 | GPIO8 | SPI SCK — **strapping pin** |
| D9 | GPIO9 | SPI MISO, BOOT button — **strapping pin** |
| D10 | GPIO10 | SPI MOSI, FSPICS0 |

There is **no user-controllable `LED_BUILTIN`** on this board — the two
on-board LEDs are power and battery-charge indicators, hardwired.

## Strapping pins: GPIO2, GPIO8, GPIO9

> **Learned the hard way, 2026-08-15.** A bring-up sketch that blinked *all*
> digital pins drove D0/GPIO2 low for 3 s out of every 6. When esptool reset
> the chip into download mode for the next upload, the running firmware was
> holding GPIO2 low at the instant boot mode was sampled → invalid boot mode →
> the ROM never started USB Serial/JTAG → the board disappeared from the USB
> bus entirely. Recovered with the BOOT-button procedure below. See
> [Recovering a board that will not enumerate](#recovering-a-board-that-will-not-enumerate).
>
> **Rule: never drive GPIO2, GPIO8 or GPIO9 low from firmware unless you have
> a specific reason.** It is not only external wiring that can strand the
> board — your own code can, and it will do it at the worst moment, because
> the host resets the chip precisely when you are trying to reflash it.

These three set the boot mode while the chip is coming out of reset. Driving
them as ordinary outputs *after* boot is perfectly fine — the risk is about
what holds them at the reset instant, whether that is your circuit **or your
firmware**:

- **GPIO9** is tied to the BOOT button with a pull-up. Held LOW at reset →
  the chip enters serial download mode instead of running your firmware.
- **GPIO8** must read HIGH at reset for a normal boot.
- **GPIO2** must read HIGH at reset for a normal boot.

A plain LED + series resistor to GND on one of these pins is enough to break
booting: the LED barely conducts below its forward voltage, so the pin settles
around ~1.8 V against the weak internal pull-up — below the ~2.5 V logic-high
threshold at 3.3 V.

Safe options when you need an indicator on D0 / D8 / D9:

1. Wire the LED **active-low**: `3V3 → LED → resistor → GPIO`. The pin sinks
   current to light it, and it presents a pull-*up* at boot.
2. Drive the LED through a MOSFET / buffer / LED-driver IC, so the GPIO only
   sees a high-impedance gate.
3. Just use the other eight pins for anything indicator-shaped.

### Which pin fails how

| Pin | Held low at reset | Severity |
|---|---|---|
| GPIO9 (D9) | Joint download boot | Benign — this is what the BOOT button does on purpose |
| GPIO8 (D8) | Blocks a normal boot | Bad, but still recoverable over USB |
| GPIO2 (D0) | **Invalid boot mode** | **Worst** — USB Serial/JTAG never comes up, board vanishes from the bus |

GPIO2 is the dangerous one: there is no button on it, and the failure removes
the very interface you would use to fix it.

## Recovering a board that will not enumerate

Symptom: no `/dev/ttyACM*`, and nothing matching VID `303a` or `2886` in
`lsusb` — the board is not on the USB bus at all.

Per [Seeed's troubleshooting notes](https://wiki.seeedstudio.com/XIAO_ESP32C3_Getting_Started/):

1. Unplug the XIAO from USB.
2. Press and **hold the BOOT button**.
3. **While still holding BOOT**, plug the USB-C cable back in.
4. Release BOOT after roughly a second.

This works no matter what is in flash, because a reset releases every GPIO
back to input before any user code runs: GPIO2 floats to its default pull-up,
the button holds GPIO9 low, and the ROM enters serial download mode. Then
reflash normally with `pio run -t upload`.

Make sure nothing is wired to D0/D8/D9 while doing this. Check with:

```bash
ls /dev/ttyACM*
lsusb | grep -iE 'espressif|303a|2886'
```

A plain RESET press is worth trying first, but it will not help if the
firmware in flash re-asserts GPIO2 low on every boot — in that case only the
BOOT procedure breaks the cycle.

## UART0 vs. the serial monitor

The board manifest sets `ARDUINO_USB_CDC_ON_BOOT=1`, so Arduino's `Serial`
is the **native USB Serial/JTAG** peripheral on the USB-C connector
(GPIO18/19, not broken out). That means D6/D7 (UART0 TX/RX) are free to use
as plain GPIO without disturbing the serial monitor.

Side effect of native USB CDC: the serial port disappears from the host on
every reset/reflash and re-enumerates a moment later. That is normal, not a
fault.

## JTAG pins

GPIO4–7 (D2–D5) double as the JTAG interface. Irrelevant while debugging over
USB Serial/JTAG, but worth knowing if you ever attach an external probe.

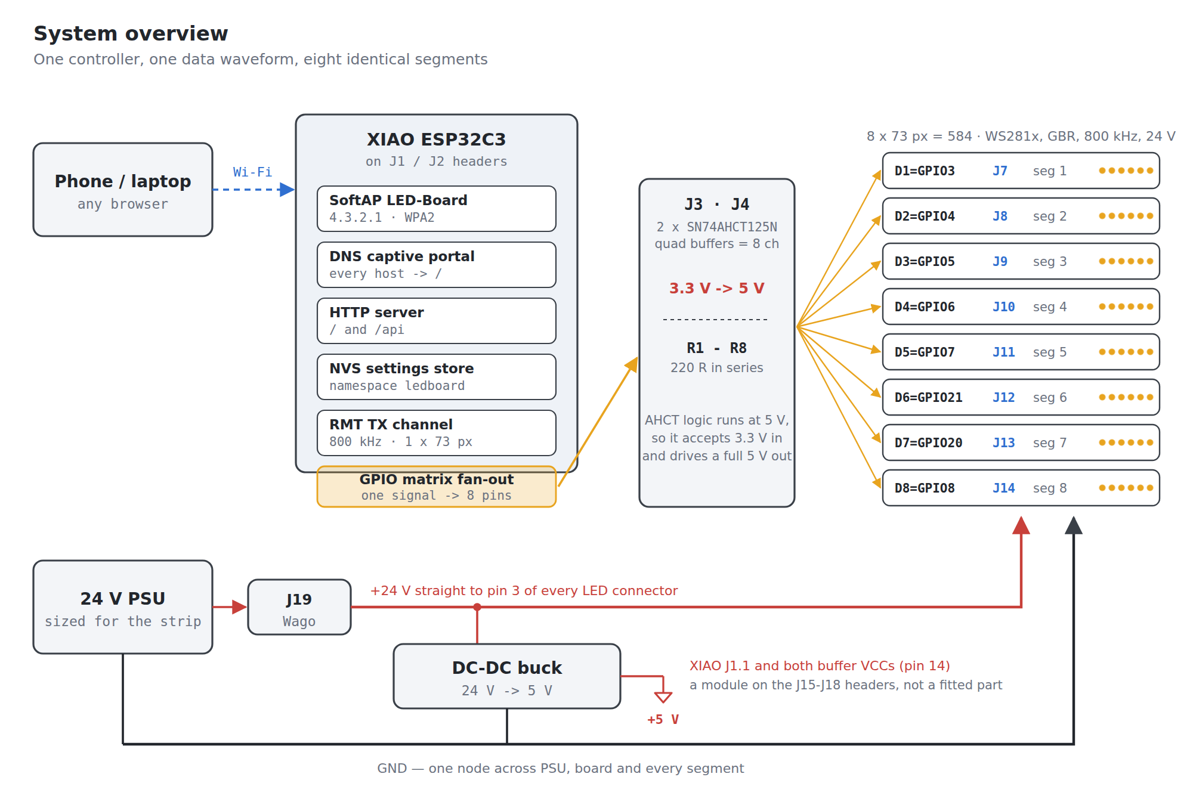
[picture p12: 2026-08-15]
images/diagrams/system-overview.png

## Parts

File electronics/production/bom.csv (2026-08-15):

Designator | Footprint | Quantity | Value | LCSC Part #
H1, H2, H3, H4 | MountingHole_4.3mm_M4_Pad | 4 | MountingHole_Pad_MP
J1, J2 | PinHeader_1x07_P2.54mm_Vertical | 2 | Conn_01x07
J10, J20 | PinHeader_1x03_P2.54mm_Vertical | 2 | LED4
J11 | PinHeader_1x03_P2.54mm_Vertical | 1 | LED5
J12 | PinHeader_1x03_P2.54mm_Vertical | 1 | LED6
J13 | PinHeader_1x03_P2.54mm_Vertical | 1 | LED7
J14 | PinHeader_1x03_P2.54mm_Vertical | 1 | LED8
J15, J17 | PinHeader_1x01_P2.54mm_Vertical | 2 | GND
J16 | PinHeader_1x01_P2.54mm_Vertical | 1 | 5V
J18 | PinHeader_1x01_P2.54mm_Vertical | 1 | 24V
J19 | Wago_734-132_1x02_P3.50mm_Vertical | 1 | Conn_01x02
J3, J4 | DIP-14_W7.62mm | 2 | SN74AHCT125N
J7 | PinHeader_1x03_P2.54mm_Vertical | 1 | LED1
J8 | PinHeader_1x03_P2.54mm_Vertical | 1 | LED2
J9 | PinHeader_1x03_P2.54mm_Vertical | 1 | LED3
R1, R2, R3, R4, R5, R6, R7, R8 | R_Axial_DIN0207_L6.3mm_D2.5mm_P7.62mm_Horizontal | 8 | 220

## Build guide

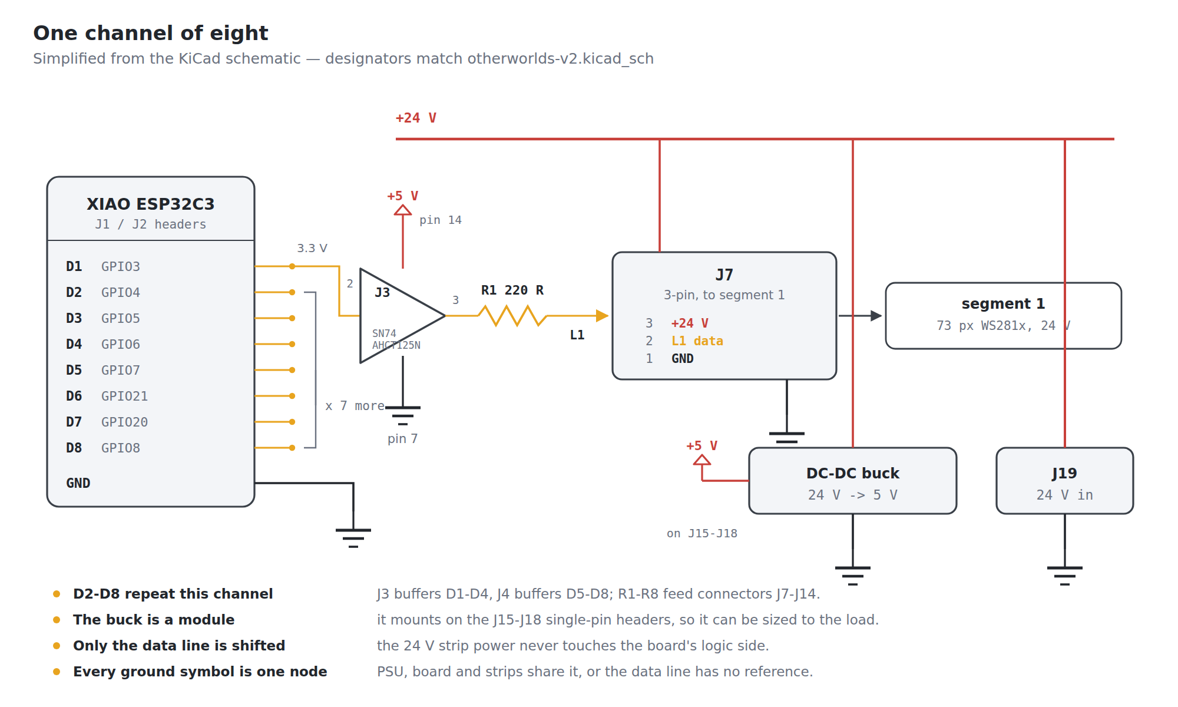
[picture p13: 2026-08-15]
images/diagrams/wiring-schematic.png

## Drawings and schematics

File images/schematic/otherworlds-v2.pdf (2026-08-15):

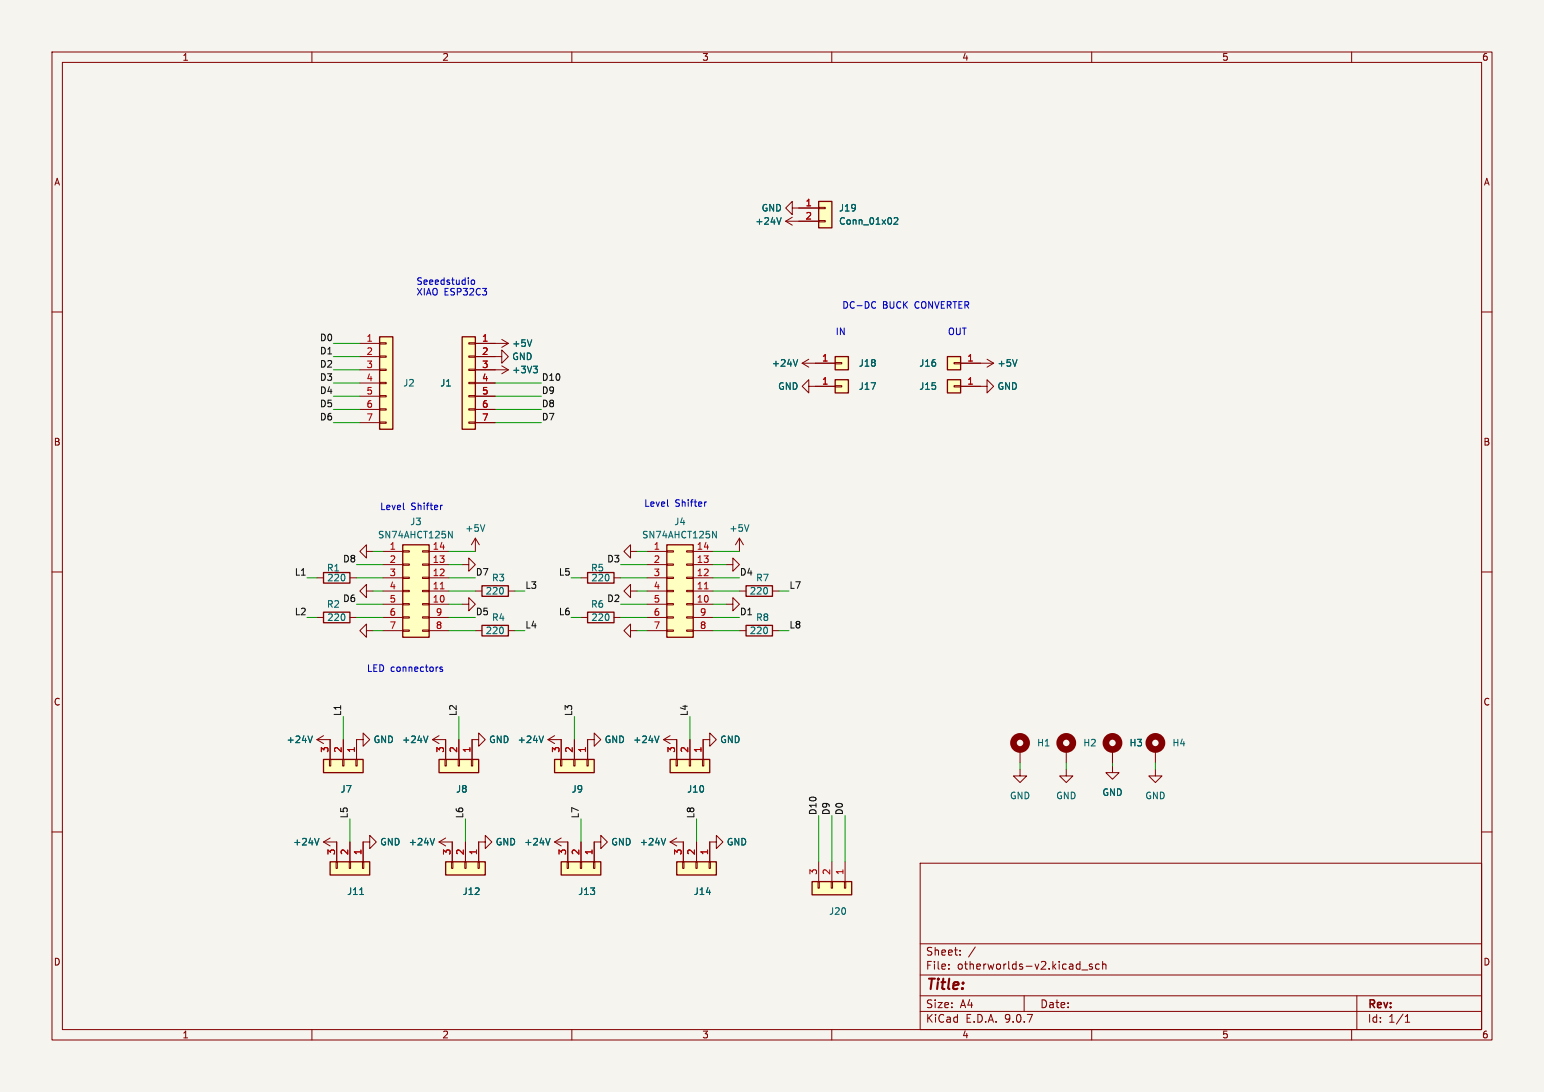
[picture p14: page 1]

Level Shifter
J3 SN74AHCT125N

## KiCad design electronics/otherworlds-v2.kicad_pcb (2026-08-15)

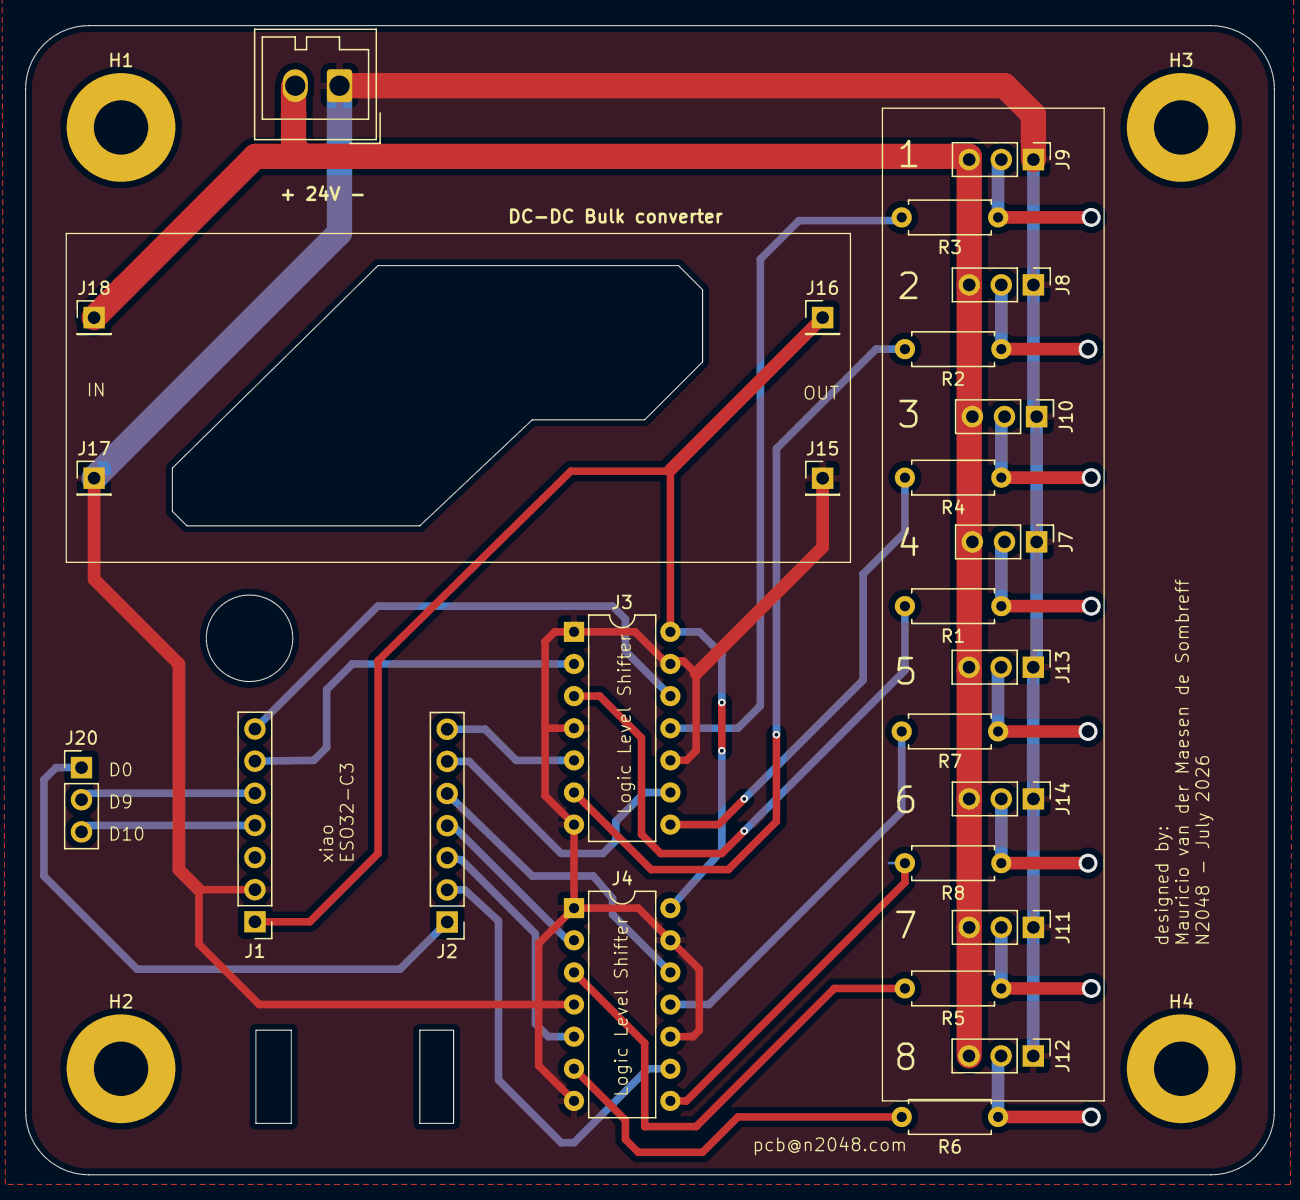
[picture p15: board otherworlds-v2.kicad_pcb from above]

Board: 2 copper layers, 98.7 x 90.9 mm, 30 parts (0 on the bottom side), 30 nets.

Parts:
H1, H2, H3, H4: MountingHole_Pad_MP; MountingHole_4.3mm_M4_Pad
J1, J2: Conn_01x07; PinHeader_1x07_P2.54mm_Vertical
J3, J4: SN74AHCT125N; DIP-14_W7.62mm
J7: LED1; PinHeader_1x03_P2.54mm_Vertical
J8: LED2; PinHeader_1x03_P2.54mm_Vertical
J9: LED3; PinHeader_1x03_P2.54mm_Vertical
J10, J20: LED4; PinHeader_1x03_P2.54mm_Vertical
J11: LED5; PinHeader_1x03_P2.54mm_Vertical
J12: LED6; PinHeader_1x03_P2.54mm_Vertical
J13: LED7; PinHeader_1x03_P2.54mm_Vertical
J14: LED8; PinHeader_1x03_P2.54mm_Vertical
J15, J17: GND; PinHeader_1x01_P2.54mm_Vertical
J16: 5V; PinHeader_1x01_P2.54mm_Vertical
J18: 24V; PinHeader_1x01_P2.54mm_Vertical
J19: Conn_01x02; Wago_734-132_1x02_P3.50mm_Vertical
R1, R2, R3, R4, R5, R6, R7, R8: 220; R_Axial_DIN0207_L6.3mm_D2.5mm_P7.62mm_Horizontal

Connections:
+5V: J1.1, J3.14 (VCC), J4.14 (VCC), J16.1
+24V: J7.3, J8.3, J9.3, J10.3, J11.3, J12.3, J13.3, J14.3, J18.1, J19.2
/D0: J2.1, J20.1
/D1: J2.2, J4.9 (3A)
/D2: J2.3, J4.5 (2A)
/D3: J2.4, J4.2 (1A)
/D4: J2.5, J4.12 (4A)
/D5: J2.6, J3.9 (3A)
/D6: J2.7, J3.5 (2A)
/D7: J1.7, J3.12 (4A)
/D8: J1.6, J3.2 (1A)
/D9: J1.5, J20.2
/D10: J1.4, J20.3
/L1: J7.2, R1.1
/L2: J8.2, R2.1
/L3: J9.2, R3.1
/L4: J10.2, R4.1
/L5: J11.2, R5.1
/L6: J12.2, R6.1
/L7: J13.2, R7.1
/L8: J14.2, R8.1
GND: J1.2, J3.1 (1/OE), J3.4 (2/OE), J3.7 (GND), J3.10 (3/OE), J3.13 (4/OE), J4.1 (1/OE), J4.4 (2/OE), J4.7 (GND), J4.10 (3/OE), J4.13 (4/OE), J7.1, J8.1, J9.1, J10.1, J11.1, J12.1, J13.1, J14.1, J15.1, J17.1, J19.1
unnamed: J3.3 (1Y), R1.2
unnamed: J3.6 (2Y), R2.2
unnamed: J3.8 (3Y), R4.2
unnamed: J3.11 (4Y), R3.2
unnamed: J4.3 (1Y), R5.2
unnamed: J4.6 (2Y), R6.2
unnamed: J4.8 (3Y), R8.2
unnamed: J4.11 (4Y), R7.2

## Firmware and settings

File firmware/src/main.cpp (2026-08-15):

/*
 * LED board - yellow fade-in, breathing hold, and a Wi-Fi control UI
 *
 * Seeed XIAO ESP32C3 driving 8 identical addressable RGB strip segments
 * through a level shifter.
 *
 * Sequence on power-up:
 *   1. FILL    - every segment fades up to the chosen colour, LED by LED from
 *                the first to the last, with a soft leading edge. All 8
 *                segments run this in parallel and in step.
 *   2. BREATHE - once full, brightness breathes between 100% and a settable
 *                floor, forever.
 *
 * The board also raises a Wi-Fi access point with a captive portal, so colour
 * and timing can be changed from a phone with no app and no internet. See
 * AP_SSID / AP_PASSWORD below. Settings persist in NVS.
 *
 * Strip settings come from a WLED configuration confirmed working on this
 * hardware:
 *   LED type     WS281x RGB (800 kHz)
 *   Colour order GBR
 *   Length       73 per segment
 *   Data GPIO    3  (segment 1)
 *
 * Output order follows the board's D1..D8 pins:
 *   seg 1 = D1 = GPIO3     seg 5 = D5 = GPIO7
 *   seg 2 = D2 = GPIO4     seg 6 = D6 = GPIO21
 *   seg 3 = D3 = GPIO5     seg 7 = D7 = GPIO20
 *   seg 4 = D4 = GPIO6     seg 8 = D8 = GPIO8
 *
 * There is no GPIO22 on the ESP32-C3 - its GPIO range is 0..21. D7 is GPIO20.
 *
 * ---------------------------------------------------------------------------
 * HOW 8 OUTPUTS ARE DRIVEN
 * ---------------------------------------------------------------------------
 * The ESP32-C3 has only 2 RMT TX channels:
 *   - FastLED 3.10.3 pins one RMT channel per controller for its lifetime, so
 *     8 strips fails with "no free tx channels" and then panics. Its
 *     README_WORKER_POOL.md describes transparent sharing, but that code is
 *     not actually in the source. Hard limit: 2 strips.
 *   - Adafruit NeoPixel with 8 instances works (it re-binds one channel per
 *     pin per show) but measured only 3 fps at 8 x 73 LEDs.
 *
 * So: ONE RMT channel transmits ONE segment's worth of data, and the GPIO
 * matrix routes that same signal to all 8 pins at once. Identical,
 * hardware-timed waveform on every segment, one transmission per frame.
 * Measured 63 fps. The segments are electrically the same signal, so they can
 * only ever show the same thing - which is what this effect wants.
 */

#include <Arduino.h>
#include <Adafruit_NeoPixel.h>
#include <WiFi.h>
#include <WebServer.h>
#include <DNSServer.h>
#include <Preferences.h>

#include "esp_rom_gpio.h"
#include "driver/gpio.h"
#include "soc/gpio_struct.h"

// ---------------------------------------------------------------------------
// Strip wiring - compile-time, matches the hardware
// ---------------------------------------------------------------------------

#define PIXEL_TYPE (NEO_GBR + NEO_KHZ800)
#define LEDS_PER_STRIP 73
#define NUM_STRIPS 8
#define MASTER_PIN 3

static const uint8_t STRIP_PINS[NUM_STRIPS] = {3, 4, 5, 6, 7, 21, 20, 8};

#define TOTAL_LEDS (LEDS_PER_STRIP * NUM_STRIPS)

static Adafruit_NeoPixel strip(LEDS_PER_STRIP, MASTER_PIN, PIXEL_TYPE);

// ---------------------------------------------------------------------------
// Access point
// ---------------------------------------------------------------------------

// Factory defaults. The live values are editable from the UI and stored in
// NVS; these are what the board falls back to if the stored pair will not
// bring an AP up, so that a bad edit can never lock you out.
static const char *AP_SSID_DEFAULT = "LED-Board";
// WPA2 needs 8-63 characters. Empty means an open network.
static const char *AP_PASS_DEFAULT = "ledboard";

static String apSsid = AP_SSID_DEFAULT;
static String apPass = AP_PASS_DEFAULT;

// Set when the UI changes credentials: the HTTP response is sent first, then
// the AP restarts a moment later, so the browser is not cut off mid-reply.
static uint32_t apRestartAtMs = 0;

// Fixed AP address. 4.3.2.1 is memorable and is what WLED uses.
static const IPAddress AP_IP(4, 3, 2, 1);
static const IPAddress AP_MASK(255, 255, 255, 0);

static DNSServer dnsServer;
static WebServer server(80);
static Preferences prefs;

// ---------------------------------------------------------------------------
// Runtime settings - all changeable from the UI, all persisted to NVS
// ---------------------------------------------------------------------------

struct Settings {
  bool on;                     // lights on/off, animated in and out
  uint8_t r, g, b;             // target colour at full brightness
  uint32_t breathePeriodMs;    // one full 100% -> floor -> 100% cycle
  uint8_t breatheMinPercent;   // floor of the breath
  uint32_t fillDurationMs;     // first LED to last; also the withdraw time
  uint16_t fillEdgeLeds;       // softness of the fill's leading edge
  uint32_t powerBudgetMa;      // see the power note below
};

// Defaults: the bright yellow this started as.
static Settings cfg = {
    .on = true,
    .r = 255,
    .g = 255,
    .b = 0,
    .breathePeriodMs = 4000,
    .breatheMinPercent = 80,
    .fillDurationMs = 4000,
    .fillEdgeLeds = 8,
    .powerBudgetMa = 3000,
};

// ---------------------------------------------------------------------------
// POWER
// ---------------------------------------------------------------------------
//
// 584 LEDs. A colour lighting two channels (yellow, cyan, magenta) costs
// roughly twice a single-channel colour; white costs three times. Full-
// brightness yellow across all segments is an estimated ~24 A at 5 V.
//
// Adafruit NeoPixel has no power management, so the limiter below finds the
// brightest scaling of the chosen colour that fits powerBudgetMa. SET THAT TO
// WHAT THE PSU ACTUALLY DELIVERS - it is now editable from the web UI, which
// makes it easy to set optimistically. It is an estimate, not a measurement.
static const uint32_t MA_PER_CHANNEL_FULL = 20;  // one channel, full, per LED
static const uint32_t MA_PER_LED_IDLE = 1;       // controller IC idle draw

static const uint16_t FRAME_INTERVAL_MS = 16;

// ---------------------------------------------------------------------------

// FILL and EMPTY share one renderer: EMPTY is literally the fill animation
// played backwards, so the LEDs withdraw in exactly the reverse order they
// arrived - the last LED to light is the first to go dark.
enum Phase { PHASE_FILL, PHASE_BREATHE, PHASE_EMPTY, PHASE_OFF };

static Phase phase = PHASE_FILL;
static uint32_t phaseStartMs = 0;
static uint32_t lastFrameMs = 0;
static uint32_t lastReportMs = 0;
static uint32_t frameCount = 0;
static uint32_t measuredFps = 0;
static uint8_t holdLevel = 255;
static uint8_t currentLevel = 0;

// --- persistence ------------------------------------------------------------

static void loadSettings() {
  // Opened read-WRITE rather than read-only: on a board that has never saved,
  // a read-only open of a missing namespace logs a scary "nvs_open failed:
  // NOT_FOUND". Read-write creates it quietly and the getters still fall back
  // to the defaults passed in.
  prefs.begin("ledboard", false);
  cfg.on = prefs.getBool("on", cfg.on);
  // isKey() guards keep Preferences from logging "nvs_get_str ... NOT_FOUND"
  // on a board that has not stored credentials yet. The defaults already hold.
  if (prefs.isKey("ssid")) {
    apSsid = prefs.getString("ssid", apSsid);
  }
  if (prefs.isKey("pass")) {
    apPass = prefs.getString("pass", apPass);
  }
  cfg.r = prefs.getUChar("r", cfg.r);
  cfg.g = prefs.getUChar("g", cfg.g);
  cfg.b = prefs.getUChar("b", cfg.b);
  cfg.breathePeriodMs = prefs.getULong("bp", cfg.breathePeriodMs);
  cfg.breatheMinPercent = prefs.getUChar("bm", cfg.breatheMinPercent);
  cfg.fillDurationMs = prefs.getULong("fd", cfg.fillDurationMs);
  cfg.fillEdgeLeds = prefs.getUShort("fe", cfg.fillEdgeLeds);
  cfg.powerBudgetMa = prefs.getULong("pb", cfg.powerBudgetMa);
  prefs.end();
}

static void saveSettings() {
  prefs.begin("ledboard", false);
  prefs.putBool("on", cfg.on);
  prefs.putUChar("r", cfg.r);
  prefs.putUChar("g", cfg.g);
  prefs.putUChar("b", cfg.b);
  prefs.putULong("bp", cfg.breathePeriodMs);
  prefs.putUChar("bm", cfg.breatheMinPercent);
  prefs.putULong("fd", cfg.fillDurationMs);
  prefs.putUShort("fe", cfg.fillEdgeLeds);
  prefs.putULong("pb", cfg.powerBudgetMa);
  prefs.end();
}

// --- power ------------------------------------------------------------------

static uint32_t estimateMilliamps(uint8_t r, uint8_t g, uint8_t b) {
  const uint32_t sum = (uint32_t)r + g + b;
  const uint32_t perLed = (MA_PER_CHANNEL_FULL * sum) / 255 + MA_PER_LED_IDLE;
  return perLed * (uint32_t)TOTAL_LEDS;
}

static uint32_t estimateAtLevel(uint8_t level) {
  return estimateMilliamps((uint8_t)(((uint16_t)cfg.r * level) / 255),
                           (uint8_t)(((uint16_t)cfg.g * level) / 255),
                           (uint8_t)(((uint16_t)cfg.b * level) / 255));
}

static uint8_t computeHoldLevel() {
  for (uint16_t level = 255; level > 0; level--) {
    if (estimateAtLevel((uint8_t)level) <= cfg.powerBudgetMa) {
      return (uint8_t)level;
    }
  }
  return 0;
}

static uint32_t colorAt(uint8_t level) {
  return strip.Color((uint8_t)(((uint16_t)cfg.r * level) / 255),
                     (uint8_t)(((uint16_t)cfg.g * level) / 255),
                     (uint8_t)(((uint16_t)cfg.b * level) / 255));
}

// --- rendering --------------------------------------------------------------

// Smoothstep 3t^2 - 2t^3 over an 8-bit triangle. Eases at both ends, which is
// what makes the breath read as breathing rather than a sawtooth.
static uint8_t breatheWave(uint8_t phase8) {
  uint16_t tri = (phase8 < 128) ? (uint16_t)phase8 * 2 : (uint16_t)(255 - phase8) * 2;
  if (tri > 255) {
    tri = 255;
  }
  const uint32_t t = tri;
  return (uint8_t)((t * t * (765 - 2 * t)) / (255UL * 255UL));
}

static uint32_t fillTravel256() {
  const uint16_t edge = cfg.fillEdgeLeds ? cfg.fillEdgeLeds : 1;
  // The front travels past the end of the strip by `edge` so the last LED
  // reaches full exactly as the phase ends, rather than being cut off
  // mid-fade.
  return (uint32_t)(LEDS_PER_STRIP + edge) * 256;
}

// Paint the strip for a given leading-edge position, in 1/256ths of an LED.
// Everything behind the front is at holdLevel, everything ahead is dark, and
// the `edge` LEDs around it are the soft gradient.
static void renderFrontAt(uint32_t front256) {
  const uint16_t edge = cfg.fillEdgeLeds ? cfg.fillEdgeLeds : 1;
  const uint32_t edge256 = (uint32_t)edge * 256;

  for (uint16_t i = 0; i < LEDS_PER_STRIP; i++) {
    const uint32_t pos256 = (uint32_t)i * 256;
    uint8_t frac;
    if (front256 <= pos256) {
      frac = 0;
    } else if ((front256 - pos256) >= edge256) {
      frac = 255;
    } else {
      frac = (uint8_t)(((front256 - pos256) * 255) / edge256);
    }
    // Gamma-correct the fade so it ramps evenly to the eye instead of
    // spending most of its apparent brightness in the first few percent.
    const uint8_t level =
        (uint8_t)(((uint16_t)Adafruit_NeoPixel::gamma8(frac) * holdLevel) / 255);
    strip.setPixelColor(i, colorAt(level));
  }
}

// One frame of the fill (forward) or the withdraw (reverse). Returns true
// once the phase has run its course.
static bool renderSweep(uint32_t elapsed, bool reverse) {
  const uint32_t duration = cfg.fillDurationMs ? cfg.fillDurationMs : 1;
  const bool done = elapsed >= duration;
  if (done) {
    elapsed = duration;
  }

  const uint32_t travel256 = fillTravel256();
  // Reverse simply runs the front from the far end back to zero, which
  // extinguishes the last LED first and the first LED last.
  const uint32_t t = reverse ? (duration - elapsed) : elapsed;
  renderFrontAt((uint32_t)((uint64_t)t * travel256 / duration));
  return done;
}

static uint8_t renderBreathe(uint32_t now) {
  const uint32_t period = cfg.breathePeriodMs ? cfg.breathePeriodMs : 1;
  const uint8_t phase8 = (uint8_t)(((now % period) * 256UL) / period);
  const uint8_t w = breatheWave(phase8);

  const uint32_t minPct = cfg.breatheMinPercent > 100 ? 100 : cfg.breatheMinPercent;
  const uint32_t span = 100 - minPct;
  const uint32_t percent = minPct + (span * w) / 255;
  const uint8_t level = (uint8_t)((holdLevel * percent) / 100);

  strip.fill(colorAt(level));
  return level;
}

// `lower` gives the UI-facing name, otherwise a padded label for serial.
static const char *phaseLabel(bool lower) {
  switch (phase) {
    case PHASE_FILL:    return lower ? "filling"  : "FILL   ";
    case PHASE_EMPTY:   return lower ? "emptying" : "EMPTY  ";
    case PHASE_OFF:     return lower ? "off"      : "OFF    ";
    case PHASE_BREATHE:
    default:            return lower ? "breathing" : "BREATHE";
  }
}

static void restartFill() {
  phase = PHASE_FILL;
  phaseStartMs = millis();
}

// Turn the lights on or off, animating in or out. If a sweep is already
// running, the new one picks up at the matching front position instead of
// snapping - so hitting off halfway through the fill withdraws from where it
// actually got to.
static void setPower(bool on) {
  if (on == cfg.on && phase != PHASE_OFF) {
    return;
  }
  const uint32_t now = millis();
  const uint32_t duration = cfg.fillDurationMs ? cfg.fillDurationMs : 1;

  // Both sweeps use the same front position, so mirroring the elapsed time
  // (e' = duration - e) makes the hand-off seamless in either direction.
  uint32_t elapsedIn = 0;
  if (phase == PHASE_FILL || phase == PHASE_EMPTY) {
    const uint32_t e = now - phaseStartMs;
    elapsedIn = duration - (e > duration ? duration : e);
  }

  cfg.on = on;
  phase = on ? PHASE_FILL : PHASE_EMPTY;
  phaseStartMs = now - elapsedIn;
}

// --- GPIO matrix fan-out ----------------------------------------------------

static bool fanOutDataSignal() {
  const uint32_t sig = GPIO.func_out_sel_cfg[MASTER_PIN].func_sel;

  // 128 is the matrix's "plain GPIO output" escape value; at or above it no
  // peripheral drives the pin, so there is nothing to copy.
  if (sig >= 128) {
    Serial.printf("  FAN-OUT FAILED: GPIO%u has no peripheral signal (func_sel=%u)\n",
                  (unsigned)MASTER_PIN, (unsigned)sig);
    return false;
  }

  Serial.printf("  RMT signal %u on GPIO%u -> mirrored to:", (unsigned)sig,
                (unsigned)MASTER_PIN);
  for (uint8_t i = 0; i < NUM_STRIPS; i++) {
    const uint8_t pin = STRIP_PINS[i];
    if (pin == MASTER_PIN) {
      continue;
    }
    gpio_reset_pin((gpio_num_t)pin);
    gpio_set_direction((gpio_num_t)pin, GPIO_MODE_OUTPUT);
    esp_rom_gpio_connect_out_signal((gpio_num_t)pin, sig, false, false);
    Serial.printf(" GPIO%u", (unsigned)pin);
  }
  Serial.println();
  return true;
}

// --- access point -----------------------------------------------------------

// SSID must be 1-32 chars. Password must be empty (open network) or 8-63
// chars - a 1-7 char password is accepted by nothing and would leave the
// board with no AP at all, so it is rejected before it can be stored.
static bool apCredsValid(const String &ssid, const String &pass) {
  if (ssid.length() < 1 || ssid.length() > 32) {
    return false;
  }
  if (pass.length() != 0 && (pass.length() < 8 || pass.length() > 63)) {
    return false;
  }
  return true;
}

static bool startAp(const String &ssid, const String &pass) {
  WiFi.softAPdisconnect(true);
  WiFi.mode(WIFI_AP);
  WiFi.softAPConfig(AP_IP, AP_IP, AP_MASK);
  return (pass.length() >= 8) ? WiFi.softAP(ssid.c_str(), pass.c_str())
                              : WiFi.softAP(ssid.c_str());
}

// Bring the AP up, falling back to the factory pair if the stored one fails.
// Without this a bad SSID/password in NVS would mean reflashing over USB to
// get back in.
static bool startApWithFallback() {
  if (apCredsValid(apSsid, apPass) && startAp(apSsid, apPass)) {
    return true;
  }
  Serial.printf("AP \"%s\" failed to start - falling back to defaults\n",
                apSsid.c_str());
  apSsid = AP_SSID_DEFAULT;
  apPass = AP_PASS_DEFAULT;
  return startAp(apSsid, apPass);
}

// ---------------------------------------------------------------------------
// Web UI - one self-contained page. Nothing external is reachable on an AP,
// so all CSS and JS are inline and the colour wheel is drawn on a canvas.
// ---------------------------------------------------------------------------

static const char INDEX_HTML[] PROGMEM = R"HTML(<!doctype html>
<html lang="en"><head>
<meta charset="utf-8">
<meta name="viewport" content="width=device-width,initial-scale=1,viewport-fit=cover">
<title>LED Board</title>
<style>
:root{--bg:#111318;--card:#1a1d24;--line:#2b3038;--fg:#e8eaed;--mut:#9aa0aa;--acc:#ffc233}
*{box-sizing:border-box}
body{margin:0;background:var(--bg);color:var(--fg);font:15px/1.5 system-ui,-apple-system,Segoe UI,Roboto,sans-serif;padding:16px;max-width:520px;margin:0 auto}
h1{font-size:19px;margin:4px 0 2px}
.sub{color:var(--mut);font-size:13px;margin-bottom:16px}
.card{background:var(--card);border:1px solid var(--line);border-radius:12px;padding:16px;margin-bottom:14px}
h2{font-size:13px;text-transform:uppercase;letter-spacing:.08em;color:var(--mut);margin:0 0 14px}
.wheelwrap{display:flex;gap:16px;align-items:center;flex-wrap:wrap;justify-content:center}
canvas{border-radius:50%;cursor:crosshair;touch-action:none;display:block}
#sw{width:74px;height:74px;border-radius:12px;border:1px solid var(--line);flex:none}
.row{display:flex;align-items:center;gap:10px;margin:12px 0}
.row label{width:64px;color:var(--mut);font-size:13px;flex:none}
input[type=range]{flex:1;accent-color:var(--acc);min-width:0}
input[type=number],input[type=text]{width:78px;background:#0e1015;border:1px solid var(--line);color:var(--fg);border-radius:8px;padding:7px 8px;font:inherit;font-size:14px;flex:none}
.val{width:56px;text-align:right;color:var(--mut);font-variant-numeric:tabular-nums;font-size:13px;flex:none}
button{background:var(--acc);color:#1a1200;border:0;border-radius:9px;padding:11px 14px;font:inherit;font-weight:600;cursor:pointer}
button.sec{background:#252a33;color:var(--fg)}
button.big{width:100%;padding:16px;font-size:16px}
button.big.off{background:#252a33;color:var(--mut)}
.btns{display:flex;gap:9px;flex-wrap:wrap;margin-top:6px}
.note{font-size:12.5px;color:var(--mut);margin-top:12px;line-height:1.45}
.warn{color:#ff9f43}
.err{color:#ff6b6b}
#hex{width:104px;text-transform:uppercase}
#ssid,#pass{width:100%}
.row.stack{flex-direction:column;align-items:stretch;gap:6px}
.row.stack label{width:auto}
</style></head><body>

<h1>LED Board</h1>
<div class="sub">8 segments &times; 73 LEDs &middot; <span id="fps">-</span> fps &middot; <span id="phase">-</span></div>

<div class="card"><button id="pwr" class="big">&nbsp;</button>
<div class="note">Turning off withdraws the LEDs in reverse: the last to light is the first to go dark.</div>
</div>

<div class="card"><h2>Colour</h2>
<div class="wheelwrap">
  <canvas id="wheel" width="200" height="200"></canvas>
  <div id="sw"></div>
</div>
<div class="row"><label>R</label><input type="range" id="rS" min="0" max="255"><span class="val" id="rV">0</span></div>
<div class="row"><label>G</label><input type="range" id="gS" min="0" max="255"><span class="val" id="gV">0</span></div>
<div class="row"><label>B</label><input type="range" id="bS" min="0" max="255"><span class="val" id="bV">0</span></div>
<div class="row"><label>Hex</label><input type="text" id="hex" maxlength="7"><input type="color" id="pick"></div>
</div>

<div class="card"><h2>Breathing</h2>
<div class="row"><label>Period</label><input type="range" id="bpS" min="500" max="20000" step="100"><span class="val" id="bpV">-</span></div>
<div class="row"><label>Floor</label><input type="range" id="bmS" min="0" max="100"><span class="val" id="bmV">-</span></div>
<div class="note">Brightness cycles between the floor and 100% of the held level. A floor of 100% holds steady with no breathing.</div>
</div>
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
void loop() {
  dnsServer.processNextRequest();
  server.handleClient();

  const uint32_t now = millis();

  // Deferred AP restart, so the HTTP reply got out before the radio drops.
  if (apRestartAtMs && now >= apRestartAtMs) {
    apRestartAtMs = 0;
    Serial.printf("Restarting AP as \"%s\"...\n", apSsid.c_str());
    dnsServer.stop();
    if (startApWithFallback()) {
      dnsServer.start(53, "*", AP_IP);
      Serial.printf("AP \"%s\" up -> http://%s/  (password: %s)\n", apSsid.c_str(),
                    AP_IP.toString().c_str(),
                    apPass.length() >= 8 ? apPass.c_str() : "<open>");
    } else {
      Serial.println(F("AP RESTART FAILED"));
    }
  }

  if ((now - lastFrameMs) < FRAME_INTERVAL_MS) {
    return;
  }
  lastFrameMs = now;

  switch (phase) {
    case PHASE_FILL:
      currentLevel = holdLevel;
      if (renderSweep(now - phaseStartMs, false)) {
        phase = PHASE_BREATHE;
        phaseStartMs = now;
        Serial.println(F("PHASE: BREATHE"));
      }
      break;

    case PHASE_EMPTY:
      currentLevel = holdLevel;
      if (renderSweep(now - phaseStartMs, true)) {
        phase = PHASE_OFF;
        Serial.println(F("PHASE: OFF"));
      }
      break;

    case PHASE_OFF:
      currentLevel = 0;
      strip.clear();
      break;

    case PHASE_BREATHE:
    default:
      currentLevel = renderBreathe(now);
      break;
  }

  strip.show();
  frameCount++;

  if ((now - lastReportMs) >= 2000) {
    measuredFps = frameCount / 2;
    Serial.printf("[%8lu ms] %s | level %3u/255 | %lu fps | est. %u mA | clients %u\n",
                  (unsigned long)now, phaseLabel(false),
                  (unsigned)currentLevel, (unsigned long)measuredFps,
                  (unsigned)estimateAtLevel(currentLevel),
                  (unsigned)WiFi.softAPgetStationNum());
    lastReportMs = now;
    frameCount = 0;
  }
}

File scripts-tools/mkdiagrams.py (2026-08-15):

#!/usr/bin/env python3
"""Generate the README diagrams as SVG.

The two animation diagrams are computed from the firmware's own integer maths
(renderFrontAt / breatheWave / gamma8), so they show what the strip actually
does rather than an artist's impression.
"""
import math
import pathlib

OUT = pathlib.Path(__file__).resolve().parent.parent / "images" / "diagrams"
OUT.mkdir(parents=True, exist_ok=True)

BG   = "#ffffff"
PANE = "#f3f5f8"
LINE = "#3a4048"
MUT  = "#6b7280"
ACC  = "#e8a41f"
RED  = "#c8403a"
BLK  = "#22262c"
BLU  = "#2f6fd0"
GRN  = "#3f9142"

FONT = "font-family='DejaVu Sans, Helvetica, Arial, sans-serif'"
MONO = "font-family='DejaVu Sans Mono, Menlo, Consolas, monospace'"


def svg(w, h, body, title):
    return (f"<svg xmlns='http://www.w3.org/2000/svg' width='{w}' height='{h}' "
            f"viewBox='0 0 {w} {h}' role='img' aria-label='{title}'>"
            f"<title>{title}</title>"
            f"<rect width='{w}' height='{h}' fill='{BG}'/>{body}</svg>")


def box(x, y, w, h, label, sub=None, fill=PANE, stroke=LINE, r=8, lsize=14):
    s = (f"<rect x='{x}' y='{y}' width='{w}' height='{h}' rx='{r}' fill='{fill}' "
         f"stroke='{stroke}' stroke-width='1.6'/>")
    cy = y + h / 2 + (0 if not sub else -7)
    s += (f"<text x='{x + w/2}' y='{cy + 5}' text-anchor='middle' {FONT} "
          f"font-size='{lsize}' font-weight='600' fill='{BLK}'>{label}</text>")
    if sub:
        s += (f"<text x='{x + w/2}' y='{cy + 23}' text-anchor='middle' {MONO} "
              f"font-size='11.5' fill='{MUT}'>{sub}</text>")
    return s


def txt(x, y, s, size=12, anchor="start", fill=BLK, mono=False, weight="400"):
    f = MONO if mono else FONT
    return (f"<text x='{x}' y='{y}' text-anchor='{anchor}' {f} font-size='{size}' "
            f"font-weight='{weight}' fill='{fill}'>{s}</text>")


def arrow(x1, y1, x2, y2, color=LINE, dash=None, width=1.8, head="a"):
    d = f" stroke-dasharray='{dash}'" if dash else ""
    return (f"<line x1='{x1}' y1='{y1}' x2='{x2}' y2='{y2}' stroke='{color}' "
            f"stroke-width='{width}'{d} marker-end='url(#{head})'/>")


def defs(colors):
    m = ""
    for name, c in colors.items():
        m += (f"<marker id='{name}' viewBox='0 0 10 10' refX='9' refY='5' "
              f"markerWidth='7' markerHeight='7' orient='auto-start-reverse'>"
              f"<path d='M 0 0 L 10 5 L 0 10 z' fill='{c}'/></marker>")
    return f"<defs>{m}</defs>"


# ---------------------------------------------------------------------------
# Shared symbols
# ---------------------------------------------------------------------------
def gnd(x, y, label=None):
    """Local ground symbol -- keeps the drawing free of one long return rail."""
    s = (f"<line x1='{x}' y1='{y}' x2='{x}' y2='{y+16}' stroke='{BLK}' stroke-width='1.6'/>"
         f"<line x1='{x-15}' y1='{y+16}' x2='{x+15}' y2='{y+16}' stroke='{BLK}' stroke-width='2.6'/>"
         f"<line x1='{x-9}' y1='{y+23}' x2='{x+9}' y2='{y+23}' stroke='{BLK}' stroke-width='2.2'/>"
         f"<line x1='{x-4}' y1='{y+30}' x2='{x+4}' y2='{y+30}' stroke='{BLK}' stroke-width='1.8'/>")
    if label:
        s += txt(x, y + 46, label, 10.5, anchor="middle", fill=MUT)
    return s


def flag(x, y, label, color=RED, up=True):
    """Power flag, drawn the way the KiCad schematic labels its rails."""
    d = -1 if up else 1
    s = (f"<path d='M {x} {y} L {x} {y+d*14} M {x-7} {y+d*14} L {x} {y+d*22} "
         f"L {x+7} {y+d*14} Z' fill='none' stroke='{color}' stroke-width='1.6' "
         f"stroke-linejoin='round'/>")
    s += txt(x, y + d * 30 + (4 if up else 10), label, 11, anchor="middle",
             fill=color, mono=True, weight="600")
    return s


# ---------------------------------------------------------------------------
# 1. System overview
# ---------------------------------------------------------------------------
def system_overview():
    W, H = 1000, 680
    s = defs({"a": LINE, "ar": RED, "ay": ACC, "ab": BLU})
    s += txt(28, 34, "System overview", 17, weight="700")
    s += txt(28, 54, "One controller, one data waveform, eight identical segments", 12.5, fill=MUT)

    # phone
    s += box(28, 120, 150, 78, "Phone / laptop", "any browser")
    s += (f"<path d='M 178 159 L 246 159' stroke='{BLU}' stroke-width='1.8' "
          f"stroke-dasharray='5 4' marker-end='url(#ab)'/>")
    s += txt(212, 148, "Wi-Fi", 11, anchor="middle", fill=BLU, mono=True)

    # controller
    s += box(248, 96, 236, 300, "", fill="#eef2f7")
    s += txt(366, 122, "XIAO ESP32C3", 14.5, anchor="middle", weight="700")
    s += txt(366, 139, "on J1 / J2 headers", 11, anchor="middle", fill=MUT, mono=True)
    rows = [("SoftAP  LED-Board", "4.3.2.1  ·  WPA2"),
            ("DNS captive portal", "every host -> /"),
            ("HTTP server", "/  and  /api"),
            ("NVS settings store", "namespace ledboard"),
            ("RMT TX channel", "800 kHz  ·  1 x 73 px")]
    for i, (a, b) in enumerate(rows):
        y = 156 + i * 47
        s += (f"<rect x='266' y='{y}' width='200' height='38' rx='6' fill='{BG}' "
              f"stroke='{LINE}' stroke-width='1.1'/>")
        s += txt(276, y + 16, a, 11.5, weight="600")
        s += txt(276, y + 30, b, 10.5, fill=MUT, mono=True)
    s += (f"<rect x='266' y='391' width='200' height='34' rx='6' fill='{ACC}' "
          f"fill-opacity='.22' stroke='{ACC}' stroke-width='1.4'/>")
    s += txt(366, 406, "GPIO matrix fan-out", 11.5, anchor="middle", weight="600")
    s += txt(366, 419, "one signal -> 8 pins", 10.5, anchor="middle", fill=MUT, mono=True)

    # level shifters
    s += box(536, 150, 130, 275, "", fill=PANE)
    s += txt(601, 176, "J3  ·  J4", 13, anchor="middle", weight="700", mono=True)
    s += txt(601, 194, "2 x SN74AHCT125N", 10.5, anchor="middle", fill=MUT, mono=True)
    s += txt(601, 208, "quad buffers = 8 ch", 10.5, anchor="middle", fill=MUT)
    s += txt(601, 246, "3.3 V  ->  5 V", 12, anchor="middle", weight="600", fill=RED)
    s += (f"<line x1='556' y1='268' x2='646' y2='268' stroke='{LINE}' "
          f"stroke-width='1' stroke-dasharray='3 3'/>")
    s += txt(601, 296, "R1 - R8", 12, anchor="middle", mono=True, weight="600")
    s += txt(601, 312, "220 R in series", 10.5, anchor="middle", fill=MUT)
    s += txt(601, 356, "AHCT logic runs at 5 V,", 10.5, anchor="middle", fill=MUT)
    s += txt(601, 371, "so it accepts 3.3 V in", 10.5, anchor="middle", fill=MUT)
    s += txt(601, 386, "and drives a full 5 V out", 10.5, anchor="middle", fill=MUT)
    s += arrow(468, 408, 534, 300, ACC, head="ay")
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

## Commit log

2026-08-15 add kicad files
    [bom.csv, designators.csv, otherworlds-v2.kicad_pcb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]
2026-08-15 fix pcb
    [bom.csv, otherworlds-v2.kicad_pcb, positions.csv]
2026-08-15 pcb docs
    [otherworlds-v2.kicad_sch]
